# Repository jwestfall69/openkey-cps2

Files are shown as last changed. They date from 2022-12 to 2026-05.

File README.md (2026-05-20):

# openkey-cps2

* [Overview](#overview)
* [Project Status](#project-status)
* [Supported Games](#supported-games)
* [Hardware](#hardware)
   * [PCB Manufacturing](#pcb-manufacturing)
   * [BOM](#bom)
   * [Assembly](#assembly)
* [Programming](#programming)
  * [Hardware](#hardware-1)
  * [Software](#software)
  * [Testing](#testing)
* [Installation](#installation)
  * [93646B-3](#93646b-3)
  * [93646B-4](#93646b-4)
  * [93646B-5](#93646b-5)
  * [93646B-6](#93646b-6)
  * [93646B-7](#93646b-7)
  * [97691A-3 (all in one)](#97691a-3-all-in-one)
  * [97691A-4 (all in one)](#97691a-4-all-in-one)

## Overview
This is an opensource/hardware implementation of an on the fly CPS2 key programmer that consists of a board thats soldered onto the CPS2 B board or the CPS2 all-in-one boards.

**NOTE**: There is a typo on the silkscreen on hardware revision 2022-12-17.  The bypass cap is listed as being 100uf, when it should be 100nf.  This typo was fixed in hardware revision 2023-01-03, however the pictures below are all from the typo'd 2022-12-17 revision.

Individual boards:<br>
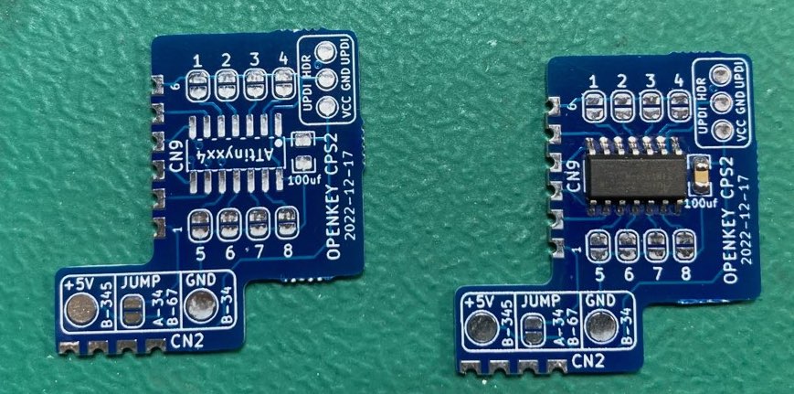
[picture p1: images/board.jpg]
board


Panel:<br>
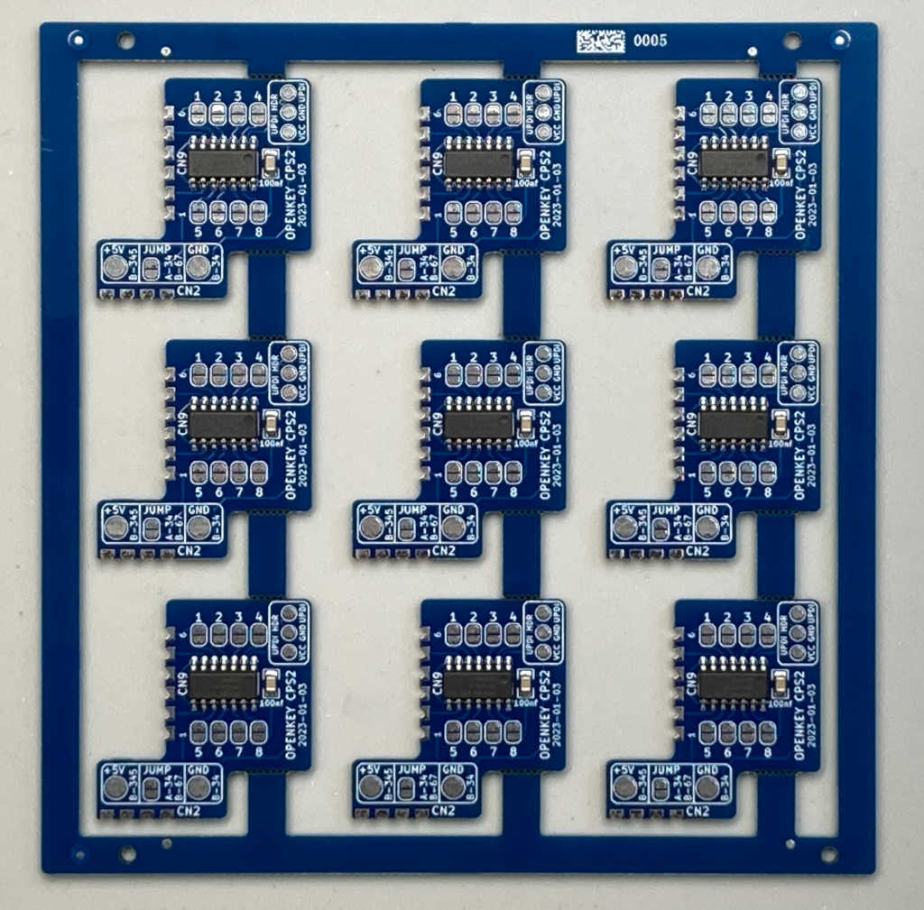
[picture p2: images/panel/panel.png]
pane


Details on *how* to program a CPS2 key data can be found in [Eduardo Cruz](http://arcadehacker.blogspot.com/)'s [write up](http://arcadehacker.blogspot.com/2016/09/capcom-cps2-security-programming-guide.html) and associated [firmware](https://github.com/ArcadeHacker/ArcadeHacker_CPS2).

Details on *what* to program can be found in MAME's [CPS2 driver](https://github.com/mamedev/mame/blob/master/src/mame/capcom/cps2.cpp) (the *.key files).

## Project Status
**PCB:** I would consider the design PCB done at this point.  I'm open to any input on changes/improvements as this is my first PCB design.

**Firmware:** Should be fulling working but more testing would be nice.  There are a lot of CPS2 games/keys.

**Documentation:** Work in progress

## Supported Games
**IMPORTANT**: You will want to program the ATtiny before soldering your game jumpers.  Specifically jumper #5 is also the programming pin on the ATtiny.  Jumping it will tie the pin to ground which will make programming impossible.

| Jumper<br>1234&nbsp;5678 | Program<br>ROM Labels | Mame<br>Rom Set | Game Names |
|:---:|:---|:---|:---|
| 0000&nbsp;0000 | nffe | 1944 | 1944: The Loop Master (Euro 000620) |
| 0000 0001 | nffj | 1944j | 1944: The Loop Master (Japan 000620) |
| 0000 0010 | nffu | 1944u | 1944: The Loop Master (USA 000620) |
| 0000 0011 | 19xe | 19xx | 19XX: The War Against Destiny (Euro 960104) |
| 0000 0100 | 09xa<br>19xa | 19xxa<br>19xxar1 | 19XX: The War Against Destiny (Asia 960104)<br>19XX: The War Against Destiny (Asia 951207) |
| 0000 0101 | 19xb | 19xxb | 19XX: The War Against Destiny (Brazil 951218) |
| 0000 0110 | 19xh | 19xxh | 19XX: The War Against Destiny (Hispanic 951218) |
| 0000 0111 | 19xj-03b<br>19xj<br>19xj | 19xxj<br>19xxjr1<br>19xxjr2 | 19XX: The War Against Destiny (Japan 960104, yellow case)<br>19XX: The War Against Destiny (Japan 951225)<br>19XX: The War Against Destiny (Japan 951207) |
| 0000 1000 | 19xu | 19xxu | 19XX: The War Against Destiny (USA 951207) |
| 0000 1001 | pwge<br>pwge | armwar<br>armwarr1 | Armored Warriors (Euro 941024)<br>Armored Warriors (Euro 941011) |
| 0000 1010 | pwga<br>pwga | armwara<br>armwarar1 | Armored Warriors (Asia 941024)<br>Armored Warriors (Asia 940920) |
| 0000 1011 | pwgb | armwarb | Armored Warriors (Brazil 941024) |
| 0000 1100 | pwgu<br>pwgu | armwaru<br>armwaru1 | Armored Warriors (USA 941024)<br>Armored Warriors (USA 940920) |
| 0000 1101 | avpe | avsp | Alien vs. Predator (Euro 940520) |
| 0000 1110 | avpa | avspa | Alien vs. Predator (Asia 940520) |
| 0000 1111 | avph | avsph | Alien vs. Predator (Hispanic 940520) |
| 0001 0000 | avpj | avspj | Alien vs. Predator (Japan 940520) |
| 0001 0001 | avpu | avspu | Alien vs. Predator (USA 940520) |
| 0001 0010 | btce | batcir | Battle Circuit (Euro 970319) |
| 0001 0011 | btca | batcira | Battle Circuit (Asia 970319) |
| 0001 0100 | btcj | batcirj | Battle Circuit (Japan 970319) |
| 0001 0101 | tkoj | choko | Janpai Puzzle Choukou (Japan 010820) |
| 0001 0110 | csce<br>csce | csclub<br>csclub1 | Capcom Sports Club (Euro 971017)<br>Capcom Sports Club (Euro 970722) |
| 0001 0111 | csca | cscluba | Capcom Sports Club (Asia 970722) |
| 0001 1000 | csch | csclubh | Capcom Sports Club (Hispanic 970722) |
| 0001 1001 | cscj<br>cscj | csclubj<br>csclubjy | Capcom Sports Club (Japan 970722)<br>Capcom Sports Club (Japan 970722, yellow case) |
| 0001 1010 | cybe | cybots | Cyberbots: Fullmetal Madness (Euro 950424) |
| 0001 1011 | cybj | cybotsj | Cyberbots: Fullmetal Madness (Japan 950420) |
| 0001 1100 | cybu | cybotsu | Cyberbots: Fullmetal Madness (USA 950424) |
| 0001 1101 | dd2e<br>dd2e<br>dd2e<br>dd2e | ddsom<br>ddsomr1<br>ddsomr2<br>ddsomr3 | Dungeons & Dragons: Shadow over Mystara (Euro 960619)<br>Dungeons & Dragons: Shadow over Mystara (Euro 960223)<br>Dungeons & Dragons: Shadow over Mystara (Euro 960209)<br>Dungeons & Dragons: Shadow over Mystara (Euro 960208) |
| 0001 1110 | dd2a<br>dd2a | ddsoma<br>ddsomar1 | Dungeons & Dragons: Shadow over Mystara (Asia 960619)<br>Dungeons & Dragons: Shadow over Mystara (Asia 960208) |
| 0001 1111 | dd2b | ddsomb | Dungeons & Dragons: Shadow over Mystara (Brazil 960223) |
| 0010 0000 | dd2h | ddsomh | Dungeons & Dragons: Shadow over Mystara (Hispanic 960223) |
| 0010 0001 | dd2j<br>dd2j<br>dd2j | ddsomj<br>ddsomjr1<br>ddsomjr2 | Dungeons & Dragons: Shadow over Mystara (Japan 960619)<br>Dungeons & Dragons: Shadow over Mystara (Japan 960206)<br>Dungeons & Dragons: Shadow over Mystara (Japan 960223) |
| 0010 0010 | dd2u<br>dd2u | ddsomu<br>ddsomur1 | Dungeons & Dragons: Shadow over Mystara (USA 960619)<br>Dungeons & Dragons: Shadow over Mystara (USA 960209) |
| 0010 0011 | dade<br>dade | ddtod<br>ddtodr1 | Dungeons & Dragons: Tower of Doom (Euro 940412)<br>Dungeons & Dragons: Tower of Doom (Euro 940113) |
| 0010 0100 | dada<br>dada | ddtoda<br>ddtodar1 | Dungeons & Dragons: Tower of Doom (Asia 940412)<br>Dungeons & Dragons: Tower of Doom (Asia 940113) |
| 0010 0101 | dadh<br>dadh<br>dadh | ddtodh<br>ddtodhr1<br>ddtodhr2 | Dungeons & Dragons: Tower of Doom (Hispanic 940412)<br>Dungeons & Dragons: Tower of Doom (Hispanic 940125)<br>Dungeons & Dragons: Tower of Doom (Hispanic 940113) |
| 0010 0110 | dadj<br>dadj<br>dadj | ddtodj<br>ddtodjr1<br>ddtodjr2 | Dungeons & Dragons: Tower of Doom (Japan 940412)<br>Dungeons & Dragons: Tower of Doom (Japan 940125)<br>Dungeons & Dragons: Tower of Doom (Japan 940113) |
| 0010 0111 | dadu<br>dadu | ddtodu<br>ddtodur1 | Dungeons & Dragons: Tower of Doom (USA 940125)<br>Dungeons & Dragons: Tower of Doom (USA 940113) |
| 0010 1000 | gmde | dimahoo | Dimahoo (Euro 000121) |
| 0010 1001 | gmdu | dimahoou | Dimahoo (USA 000121) |
| 0010 1010 | vame | dstlk | Darkstalkers: The Night Warriors (Euro 940705) |
| 0010 1011 | vama | dstlka | Darkstalkers: The Night Warriors (Asia 940705) |
| 0010 1100 | vamh | dstlkh | Darkstalkers: The Night Warriors (Hispanic 940818) |
| 0010 1101 | vamu<br>vamu | dstlku<br>dstlkur1 | Darkstalkers: The Night Warriors (USA 940818)<br>Darkstalkers: The Night Warriors (USA 940705) |
| 0010 1110 | uece | ecofghtr | Eco Fighters (World 931203) |
| 0010 1111 | ueca | ecofghtra | Eco Fighters (Asia 931203) |
| 0011 0000 | uech | ecofghtrh | Eco Fighters (Hispanic 931203) |
| 0011 0001 | uecu<br>uecu | ecofghtru<br>ecofghtru1 | Eco Fighters (USA 940215)<br>Eco Fighters (USA 931203) |
| 0011 0010 | ggwu | gigawing | Giga Wing (USA 990222) |
| 0011 0011 | ggwa | gigawinga | Giga Wing (Asia 990222) |
| 0011 0100 | ggwb | gigawingb | Giga Wing (Brazil 990222) |
| 0011 0101 | ggwh | gigawingh | Giga Wing (Hispanic 990222) |
| 0011 0110 | ggwj | gigawingj | Giga Wing (Japan 990223) |
| 0011 0111 | gmdj | gmahou | Great Mahou Daisakusen (Japan 000121) |
| 0011 1000 | hs2u | hsf2 | Hyper Street Fighter II: The Anniversary Edition (USA 040202) |
| 0011 1001 | hs2a | hsf2a | Hyper Street Fighter II: The Anniversary Edition (Asia 040202) |
| 0011 1010 | hs2j<br>hs2j | hsf2j<br>hsf2j1<br>hsf2j2 | Hyper Street Fighter II: The Anniversary Edition (Japan 040202)<br>Street Fighter II: The Anniversary Edition (Japan 040123)<br>Hyper Street Fighter II: The Anniversary Edition (Japan 031222) |
| 0011 1011 | majj | jyangoku | Jyangokushi: Haoh no Saihai (Japan 990527) |
| 0011 1100 | rm2u | megaman2 | Mega Man 2: The Power Fighters (USA 960708) |
| 0011 1101 | rm2a | megaman2a | Mega Man 2: The Power Fighters (Asia 960708) |
| 0011 1110 | rm2h | megaman2h | Mega Man 2: The Power Fighters (Hispanic 960712) |
| 0011 1111 | rcmu<br>rcmu<br>rcmu | mmancp2u<br>mmancp2ur1<br>mmancp2ur2 | Mega Man: The Power Battle (CPS2, USA 951006, SAMPLE Version)<br>Mega Man: The Power Battle (CPS2, USA 950926, SAMPLE Version)<br>Mega Man: The Power Battle (CPS2, USA 950925, SAMPLE Version) |
| 0100 0000 | sys_rom1 | mmatrix | Mars Matrix: Hyper Solid Shooting (USA 000412) |
| 0100 0001 | mmxa | mmatrixa | Mars Matrix: Hyper Solid Shooting (Asia 000412) |
| 0100 0010 | mmxj | mmatrixj | Mars Matrix: Hyper Solid Shooting (Japan 000412) |
| 0100 0011 | mpne<br>mpn_03a<br>mpnj<br>mpne<br>mpnu | mpang<br>mpanga<br>mpangj<br>mpangr1<br>mpangu | Mighty! Pang (Euro 001010)<br>Mighty! Pang (Asia 001010)<br>Mighty! Pang (Japan 001011)<br>Mighty! Pang (Euro 000925)<br>Mighty! Pang (USA 001010) |
| 0100 0100 | mshe | msh | Marvel Super Heroes (Euro 951024) |
| 0100 0101 | msha | msha | Marvel Super Heroes (Asia 951024) |
| 0100 0110 | mshb<br>mshb | mshb<br>mshbr1 | Marvel Super Heroes (Brazil 951117)<br>Marvel Super Heroes (Brazil 951024) |
| 0100 0111 | mshh | mshh | Marvel Super Heroes (Hispanic 951117) |
| 0100 1000 | mshj<br>mshj | mshj<br>mshjr1 | Marvel Super Heroes (Japan 951117)<br>Marvel Super Heroes (Japan 951024) |
| 0100 1001 | mshu | mshu | Marvel Super Heroes (USA 951024) |
| 0100 1010 | mvse | mshvsf | Marvel Super Heroes Vs. Street Fighter (Euro 970625) |
| 0100 1011 | mvsa<br>mvsa | mshvsfa<br>mshvsfa1 | Marvel Super Heroes Vs. Street Fighter (Asia 970625)<br>Marvel Super Heroes Vs. Street Fighter (Asia 970620) |
| 0100 1100 | mvsb<br>mvsb | mshvsfb<br>mshvsfb1 | Marvel Super Heroes Vs. Street Fighter (Brazil 970827)<br>Marvel Super Heroes Vs. Street Fighter (Brazil 970625) |
| 0100 1101 | mvsh | mshvsfh | Marvel Super Heroes Vs. Street Fighter (Hispanic 970625) |
| 0100 1110 | mvsj<br>mvsj<br>mvsj | mshvsfj<br>mshvsfj1<br>mshvsfj2 | Marvel Super Heroes Vs. Street Fighter (Japan 970707)<br>Marvel Super Heroes Vs. Street Fighter (Japan 970702)<br>Marvel Super Heroes Vs. Street Fighter (Japan 970625) |
| 0100 1111 | mvsu<br>mvsu | mshvsfu<br>mshvsfu1 | Marvel Super Heroes Vs. Street Fighter (USA 970827)<br>Marvel Super Heroes Vs. Street Fighter (USA 970625) |
| 0101 0000 | mvce<br>mvce | mvsc<br>mvscr1 | Marvel Vs. Capcom: Clash of Super Heroes (Euro 980123)<br>Marvel Vs. Capcom: Clash of Super Heroes (Euro 980112) |
| 0101 0001 | mvca<br>mvca | mvsca<br>mvscar1 | Marvel Vs. Capcom: Clash of Super Heroes (Asia 980123)<br>Marvel Vs. Capcom: Clash of Super Heroes (Asia 980112) |
| 0101 0010 | mvcb | mvscb | Marvel Vs. Capcom: Clash of Super Heroes (Brazil 980123) |
| 0101 0011 | mvch | mvsch | Marvel Vs. Capcom: Clash of Super Heroes (Hispanic 980123) |
| 0101 0100 | mvcj<br>mvcj<br>mvc_ja | mvscj<br>mvscjr1<br>mvscjsing | Marvel Vs. Capcom: Clash of Super Heroes (Japan 980123)<br>Marvel Vs. Capcom: Clash of Super Heroes (Japan 980112)<br>Marvel Vs. Capcom: Clash of Super Heroes (Japan 980123) (Single PCB) |
| 0101 0101 | mvcu<br>mvcu | mvscu<br>mvscur1 | Marvel Vs. Capcom: Clash of Super Heroes (USA 980123)<br>Marvel Vs. Capcom: Clash of Super Heroes (USA 971222) |
| 0101 0110 | vphe | nwarr | Night Warriors: Darkstalkers' Revenge (Euro 950316) |
| 0101 0111 | vpha | nwarra | Night Warriors: Darkstalkers' Revenge (Asia 950302) |
| 0101 1000 | vphb | nwarrb | Night Warriors: Darkstalkers' Revenge (Brazil 950403) |
| 0101 1001 | vphh | nwarrh | Night Warriors: Darkstalkers' Revenge (Hispanic 950403) |
| 0101 1010 | vphu | nwarru | Night Warriors: Darkstalkers' Revenge (USA 950406) |
| 0101 1011 | pcfj | pfghtj | Pocket Fighter (Japan 970904) |
| 0101 1100 | pwgj<br>pwgj | pgear<br>pgearr1 | Powered Gear: Strategic Variant Armor Equipment (Japan 941024)<br>Powered Gear: Strategic Variant Armor Equipment (Japan 940916) |
| 0101 1101 | pgau | progear | Progear (USA 010117) |
| 0101 1110 | pgaa | progeara | Progear (Asia 010117) |
| 0101 1111 | pgaj | progearj | Progear no Arashi (Japan 010117) |
| 0110 0000 | pl2e<br>pl2j<br>pl2j | pzloop2<br>pzloop2j<br>pzloop2jr1 | Puzz Loop 2 (Euro 010302)<br>Puzz Loop 2 (Japan 010226)<br>Puzz Loop 2 (Japan 010205) |
| 0110 0001 | tqzj | qndream | Quiz Nanairo Dreams: Nijiirochou no Kiseki (Japan 96086) |
| 0110 0010 | smbe | ringdest | Ring of Destruction: Slammasters II (Euro 940902) |
| 0110 0011 | smba | ringdesta | Ring of Destruction: Slammasters II (Asia 940831) |
| 0110 0100 | smbb<br>smbh | ringdestb<br>ringdesth | Ring of Destruction: Slammasters II (Brazil 940902)<br>Ring of Destruction: Slammasters II (Hispanic 940902) |
| 0110 0101 | rcmj | rmancp2j | Rockman: The Power Battle (CPS2, Japan 950922) |
| 0110 0110 | rm2j | rockman2j | Rockman 2: The Power Fighters (Japan 960708) |
| 0110 0111 | sfze<br>sfze<br>sfze<br>sfze | sfa<br>sfar1<br>sfar2<br>sfar3 | Street Fighter Alpha: Warriors' Dreams (Euro 950727)<br>Street Fighter Alpha: Warriors' Dreams (Euro 950718)<br>Street Fighter Alpha: Warriors' Dreams (Euro 950627)<br>Street Fighter Alpha: Warriors' Dreams (Euro 950605) |
| 0110 1000 | sz2e | sfa2 | Street Fighter Alpha 2 (Euro 960229) |
| 0110 1001 | sz2u<br>sz2u | sfa2u<br>sfa2ur1 | Street Fighter Alpha 2 (USA 960430)<br>Street Fighter Alpha 2 (USA 960306) |
| 0110 1010 | sz3e | sfa3 | Street Fighter Alpha 3 (Euro 980904) |
| 0110 1011 | sz3b | sfa3b | Street Fighter Alpha 3 (Brazil 980629) |
| 0110 1100 | sz3h<br>sz3h | sfa3h<br>sfa3hr1 | Street Fighter Alpha 3 (Hispanic 980904)<br>Street Fighter Alpha 3 (Hispanic 980629) |
| 0110 1101 | sz3u<br>sz3u<br>sz3-usam_03 | sfa3u<br>sfa3ur1<br>sfa3us | Street Fighter Alpha 3 (USA 980904)<br>Street Fighter Alpha 3 (USA 980629)<br>Street Fighter Alpha 3 (USA 980616, SAMPLE Version) |
| 0110 1110 | sfzu | sfau | Street Fighter Alpha: Warriors' Dreams (USA 950627) |
| 0110 1111 | sz2a | sfz2a | Street Fighter Zero 2 (Asia 960227) |
| 0111 0000 | szaa<br>szaa | sfz2al<br>sfz2alr1 | Street Fighter Zero 2 Alpha (Asia 960826)<br>Street Fighter Zero 2 Alpha (Asia 960805) |
| 0111 0001 | szab | sfz2alb | Street Fighter Zero 2 Alpha (Brazil 960813) |
| 0111 0010 | szah | sfz2alh | Street Fighter Zero 2 Alpha (Hispanic 960813) |
| 0111 0011 | szaj | sfz2alj | Street Fighter Zero 2 Alpha (Japan 960805) |
| 0111 0100 | sz2b<br>sz2b | sfz2b<br>sfz2br1 | Street Fighter Zero 2 (Brazil 960531)<br>Street Fighter Zero 2 (Brazil 960304) |
| 0111 0101 | sz2h | sfz2h | Street Fighter Zero 2 (Hispanic 960304) |
| 0111 0110 | sz2j<br>sz2j | sfz2j<br>sfz2jr1 | Street Fighter Zero 2 (Japan 960430)<br>Street Fighter Zero 2 (Japan 960227) |
| 0111 0111 | sz2n | sfz2n | Street Fighter Zero 2 (Oceania 960229) |
| 0111 1000 | sz3a<br>sz3a | sfz3a<br>sfz3ar1 | Street Fighter Zero 3 (Asia 980904)<br>Street Fighter Zero 3 (Asia 980701) |
| 0111 1001 | sz3j<br>sz3j<br>sz3j | sfz3j<br>sfz3jr1<br>sfz3jr2 | Street Fighter Zero 3 (Japan 980904)<br>Street Fighter Zero 3 (Japan 980727)<br>Street Fighter Zero 3 (Japan 980629) |
| 0111 1010 | sfza<br>sfza | sfza<br>sfzar1 | Street Fighter Zero (Asia 950627)<br>Street Fighter Zero (Asia 950605) |
| 0111 1011 | sfzb<br>sfzb | sfzb<br>sfzbr1 | Street Fighter Zero (Brazil 951109)<br>Street Fighter Zero (Brazil 950727) |
| 0111 1100 | sfzh<br>sfzh | sfzh<br>sfzhr1 | Street Fighter Zero (Hispanic 950718)<br>Street Fighter Zero (Hispanic 950627) |
| 0111 1101 | sfzj<br>sfzj<br>sfzj | sfzj<br>sfzjr1<br>sfzjr2 | Street Fighter Zero (Japan 950727)<br>Street Fighter Zero (Japan 950627)<br>Street Fighter Zero (Japan 950605) |
| 0111 1110 | pcfu | sgemf | Super Gem Fighter Mini Mix (USA 970904) |
| 0111 1111 | pcfa | sgemfa | Super Gem Fighter: Mini Mix (Asia 970904) |
| 1000 0000 | pcfh | sgemfh | Super Gem Fighter: Mini Mix (Hispanic 970904) |
| 1000 0001 | smbj<br>smbj | smbomb<br>smbombr1 | Super Muscle Bomber: The International Blowout (Japan 940831)<br>Super Muscle Bomber: The International Blowout (Japan 940808) |
| 1000 0010 | pzfe | spf2t | Super Puzzle Fighter II Turbo (Euro 960529) |
| 1000 0011 | pzfa | spf2ta | Super Puzzle Fighter II Turbo (Asia 960529) |
| 1000 0100 | pzfh | spf2th | Super Puzzle Fighter II Turbo (Hispanic 960531) |
| 1000 0101 | pzfu | spf2tu | Super Puzzle Fighter II Turbo (USA 960620) |
| 1000 0110 | pzfj | spf2xj | Super Puzzle Fighter II X (Japan 960531) |
| 1000 0111 | ssfe<br>ssfe | ssf2<br>ssf2r1 | Super Street Fighter II: The New Challengers (World 931005)<br>Super Street Fighter II: The New Challengers (World 930911) |
| 1000 1000 | ssfa<br>ssfa | ssf2a<br>ssf2ar1 | Super Street Fighter II: The New Challengers (Asia 931005)<br>Super Street Fighter II: The New Challengers (Asia 930914) |
| 1000 1001 | ssfh | ssf2h | Super Street Fighter II: The New Challengers (Hispanic 930911) |
| 1000 1010 | ssfj<br>ssfj<br>ssfj | ssf2j<br>ssf2jr1<br>ssf2jr2 | Super Street Fighter II: The New Challengers (Japan 931005)<br>Super Street Fighter II: The New Challengers (Japan 930911)<br>Super Street Fighter II: The New Challengers (Japan 930910) |
| 1000 1011 | ssfh | ssf2t | Super Street Fighter II Turbo (World 940223) |
| 1000 1100 | sfxa | ssf2ta | Super Street Fighter II Turbo (Asia 940223) |
| 1000 1101 | ssfe<br>ssfe | ssf2tb<br>ssf2tbr1 | Super Street Fighter II: The Tournament Battle (World 931119)<br>Super Street Fighter II: The Tournament Battle (World 930911) |
| 1000 1110 | ssfa | ssf2tba | Super Street Fighter II: The Tournament Battle (Asia 931005) |
| 1001 0000 | ssftj<br>ssfj | ssf2tbj<br>ssf2tbj1 | Super Street Fighter II: The Tournament Battle (Japan 931005)<br>Super Street Fighter II: The Tournament Battle (Japan 930911) |
| 1001 0001 | ssfu | ssf2tbu | Super Street Fighter II: The Tournament Battle (USA 930911) |
| 1001 0010 | sfxh | ssf2th | Super Street Fighter II Turbo (Hispanic 940223) |
| 1001 0011 | sfxu<br>sfxu | ssf2tu<br>ssf2tur1 | Super Street Fighter II Turbo (USA 940323)<br>Super Street Fighter II Turbo (USA 940223) |
| 1001 0100 | ssfu<br>ssfu | ssf2u<br>ssf2us2 | Super Street Fighter II: The New Challengers (USA 930911)<br> |
| 1001 0101 | sfxj<br>sfxj | ssf2xj<br>ssf2xjr1 | Super Street Fighter II X: Grand Master Challenge (Japan 940311)<br>Super Street Fighter II X: Grand Master Challenge (Japan 940223) |
| 1001 0110 | sfxo | ssf2xjr1r | Super Street Fighter II X: Grand Master Challenge (Japan 940223 rent version) |
| 1001 0111 | uecj | uecology | Ultimate Ecology (Japan 931203) |
| 1001 1000 | vamj<br>vamj<br>vamj | vampj<br>vampja<br>vampjr1 | Vampire: The Night Warriors (Japan 940705)<br>Vampire: The Night Warriors (Japan 940705 alt)<br>Vampire: The Night Warriors (Japan 940630) |
| 1001 1001 | vh2j<br>vh2j | vhunt2<br>vhunt2r1 | Vampire Hunter 2: Darkstalkers Revenge (Japan 970929)<br>Vampire Hunter 2: Darkstalkers Revenge (Japan 970913) |
| 1001 1010 | vphj<br>vphj<br>vphjstop<br>vphj | vhuntj<br>vhuntjr1<br>vhuntjr1s<br>vhuntjr2 | Vampire Hunter: Darkstalkers' Revenge (Japan 950316)<br>Vampire Hunter: Darkstalkers' Revenge (Japan 950307)<br>Vampire Hunter: Darkstalkers' Revenge (Japan 950307 stop version)<br>Vampire Hunter: Darkstalkers' Revenge (Japan 950302) |
| 1001 1011 | vm3e | vsav | Vampire Savior: The Lord of Vampire (Euro 970519) |
| 1001 1100 | vs2j | vsav2 | Vampire Savior 2: The Lord of Vampire (Japan 970913) |
| 1001 1101 | vm3a | vsava | Vampire Savior: The Lord of Vampire (Asia 970519) |
| 1001 1110 | vm3b | vsavb | Vampire Savior: The Lord of Vampire (Brazil 970519) |
| 1001 1111 | vm3h | vsavh | Vampire Savior: The Lord of Vampire (Hispanic 970519) |
| 1010 0000 | vm3j | vsavj | Vampire Savior: The Lord of Vampire (Japan 970519) |
| 1010 0001 | vm3u | vsavu | Vampire Savior: The Lord of Vampire (USA 970519) |
| 1010 0010 | xmne<br>xmne | xmcota<br>xmcotar1 | X-Men: Children of the Atom (Euro 950331)<br>X-Men: Children of the Atom (Euro 950105) |
| 1010 0011 | xmna<br>xmna<br>xmna | xmcotaa<br>xmcotaar1<br>xmcotaar2 | X-Men: Children of the Atom (Asia 950105)<br>X-Men: Children of the Atom (Asia 941219)<br>X-Men: Children of the Atom (Asia 941217) |
| 1010 0100 | xmnb | xmcotab | X-Men: Children of the Atom (Brazil 950331) |
| 1010 0101 | xmnh<br>xmnh | xmcotah<br>xmcotahr1 | X-Men: Children of the Atom (Hispanic 950331)<br>X-Men: Children of the Atom (Hispanic 950105) |
| 1010 0110 | xmnj<br>xmnj<br>xmnj<br>xmnj<br>xmno | xmcotaj<br>xmcotaj1<br>xmcotaj2<br>xmcotaj3<br>xmcotajr | X-Men: Children of the Atom (Japan 950105)<br>X-Men: Children of the Atom (Japan 941222)<br>X-Men: Children of the Atom (Japan 941219)<br>X-Men: Children of the Atom (Japan 941217)<br>X-Men: Children of the Atom (Japan 941208 rent version) |
| 1010 0111 | xmnu | xmcotau | X-Men: Children of the Atom (USA 950105) |
| 1010 1000 | xvse<br>xvse | xmvsf<br>xmvsfr1 | X-Men Vs. Street Fighter (Euro 961004)<br>X-Men Vs. Street Fighter (Euro 960910) |
| 1010 1001 | xvsa<br>xvsa<br>xvsa<br>xvsa | xmvsfa<br>xmvsfar1<br>xmvsfar2<br>xmvsfar3 | X-Men Vs. Street Fighter (Asia 961023)<br>X-Men Vs. Street Fighter (Asia 961004)<br>X-Men Vs. Street Fighter (Asia 960919)<br>X-Men Vs. Street Fighter (Asia 960910) |
| 1010 1010 | xvsb | xmvsfb | X-Men Vs. Street Fighter (Brazil 961023) |
| 1010 1011 | xvsh | xmvsfh | X-Men Vs. Street Fighter (Hispanic 961004) |
| 1010 1100 | xvsj<br>xvsj<br>xvsj<br>xvsj | xmvsfj<br>xmvsfjr1<br>xmvsfjr2<br>xmvsfjr3<br>xmvsfjr4 | X-Men Vs. Street Fighter (Japan 970113)<br>X-Men Vs. Street Fighter (Japan 961023)<br>X-Men Vs. Street Fighter (Japan 961004)<br>X-Men Vs. Street Fighter (Japan 960910)<br>X-Men Vs. Street Fighter (Japan 960909) |
| 1010 1101 | xvsu<br>xvsu<br>xvsu | xmvsfu<br>xmvsfur1<br>xmvsfur2 | X-Men Vs. Street Fighter (USA 961023)<br>X-Men Vs. Street Fighter (USA 961004)<br>X-Men Vs. Street Fighter (USA 960910) |
| 1010 1110 | | | Phoenix Key (0xff filled) |

## Hardware
### PCB Manufacturing
For thickness I've been using 1mm, but standard 1.6mm will work fine too.

The board has 2 sets of castellated holes (through holes cut in half on the edge of the board).  When ordering make sure you pick the option for castellated holes as they require special processing.  If you don't pick the option, your castellated holes will likely be mangled and look like this

**Mangled Castellated Holes**<br>
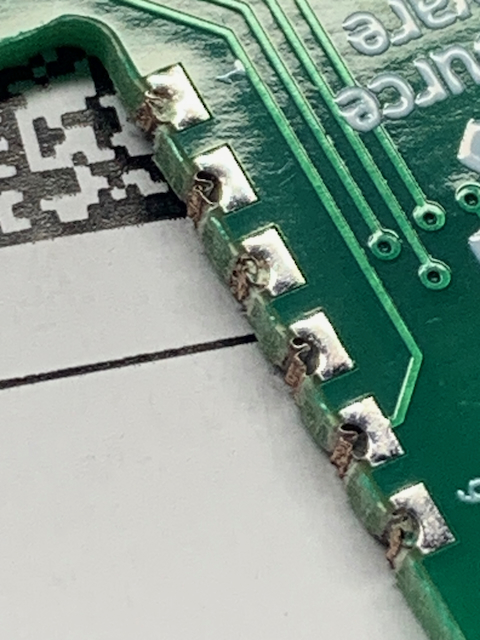
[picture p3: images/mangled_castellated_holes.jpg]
mangled castellated holes


I've been using [jlcpcb](https://jlcpcb.com/) for PCB manufacturing.  For them, picking castellated holes adds around a $40 fee to the order.  They also seem to have an unwritten limit of 30 PCBs per order that have castellated holes.  If you go above this they may reject your order or ask you if its ok to remove the castellated holes option (don't do it!).

If you want more then 30 PCBs or want them assembled you will want to use the
panel version of openkey-cps2.  More detail regarding this can be found in [PANEL.md](PANEL.md).

### BOM
| Description | Part Number | DigiKey | Mouser | Notes |
|---|---|---|---|---|
| ATtiny404 20Mhz | ATTINY404-SSN | [ATTINY404-SSN-ND](https://www.digikey.com/en/products/detail/microchip-technology/ATTINY404-SSN/9947546) | [556-ATTINY404-SSNR](https://www.mouser.com/ProductDetail/Microchip-Technology-Atmel/ATTINY404-SSNR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) | Other ATtiny tinyAVR 0/1/2-series models should be viable as well.  The code compiles to a little over 3K in size, so any that have 4K or more of flash should work.  Just note I have only tested with 404s |
| 100nf / 0.1uf SMD Ceramic Capacitor 0805 Size | | | | |

### Assembly
Nothing special here just install the ATtiny and the bypass cap.

**IMPORTANT**: You will want to program the ATtiny before soldering your game jumpers.  Specifically jumper #5 is also the programming pin on the ATtiny.  Jumping it will tie the pin to ground which will make programming impossible.

## Programming
### Hardware
Programming is done with a UPDI programmer.  I've been using this one:

[Serial UPDI Programmer for ATmega 0-Series, or ATtiny 0-Series or 1-Series, or AVR DA or AVR DB](https://www.amazon.com/dp/B09X64YRLD?psc=1&ref=ppx_yo2ov_dt_b_product_details)

Note: This programmer (and likely others) has a switch for 3.3V and 5V.  Set it to 5V.

The openkey-cps2 programming port consists of 3x pads (VCC, GND, UPDI) that will need to be connected to the programmer.  I've been using a short 3 pin female to female IDC cable with [pogo pins](https://www.amazon.com/dp/B00X7C8PGE?psc=1&ref=ppx_yo2ov_dt_b_product_details) on one end to do this.  Additionally you could probably use something like [this](https://www.amazon.com/dp/B09MGG4C6X?ref=ppx_yo2ov_dt_b_product_details&th=1) if you are going to be programming a bunch.

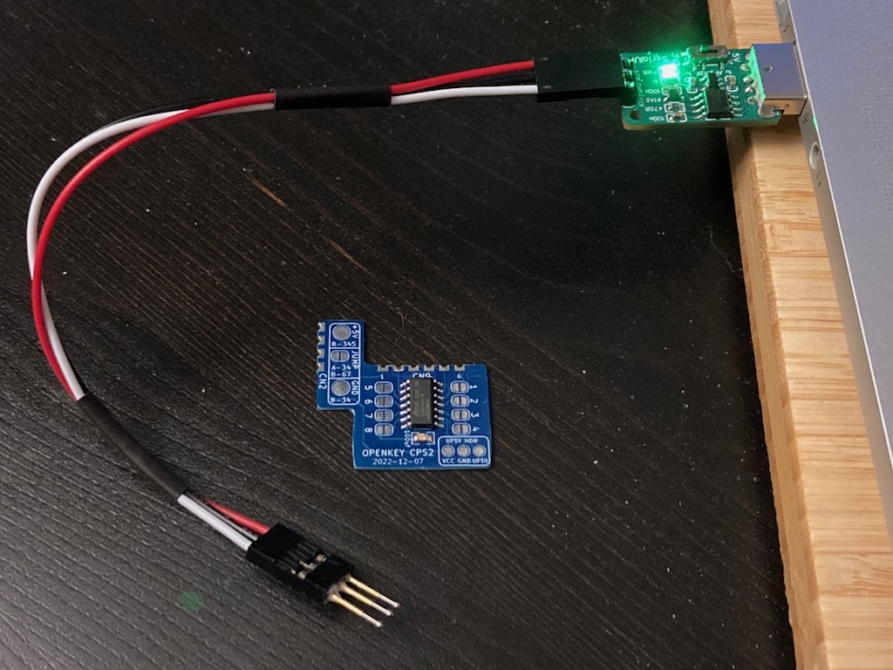
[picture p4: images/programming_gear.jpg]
programming gear


Of course be sure you properly orient the board so the labeled pads match up.  vcc to vcc, gnd to gnd, and updi to updi.

### Software
For software I've been using the [Arduino IDE](https://www.arduino.cc/en/software/OldSoftwareReleases) with [megaTinyCore](https://github.com/SpenceKonde/megaTinyCore), which adds support for tinyAVR 0/1/2-Series MCUs.

**NOTE**: The makers of megaTinyCore currently recommend using Arduino IDE version 1.8.13 for best compatibility.
 2.0 definitely does not work!

To install the megaTinyCore you, should just need to add http://drazzy.com/package_drazzy.com_index.json to "Addit
ional Boards Manager URLs" in the settings for the Arduino IDE.

From there you need to configure the board/programming settings.  I've been using these:

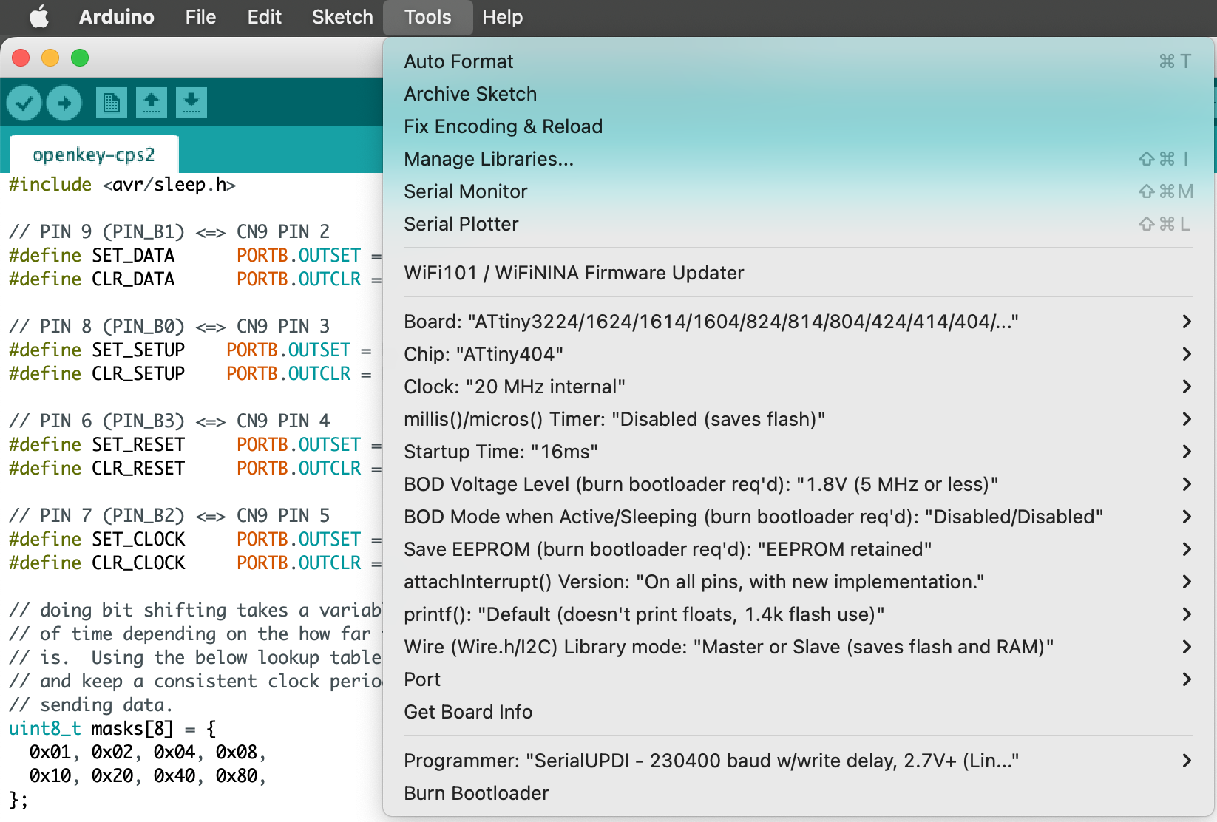
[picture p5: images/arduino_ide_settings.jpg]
arduino ide settings


### Testing
If you are selling or giving away the openkey-cps2's that you have assembled/programmed its nice to be able to test them first.  This section explains how you can test the board without having to install it.

You will need to get your hands on a "1944: The Loop Master (Euro 000620)" in a 93646B-6 or 93646B-7 B board.  For mine I just made a conversion using the 1944 mame romset.  This specific game is needed because its game jumper 0000 0000.

Additionally you will need to create the following cable

Side A:<br>
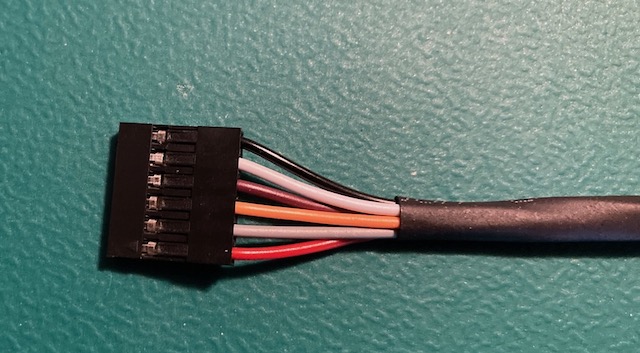
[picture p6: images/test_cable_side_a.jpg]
test cable side a


Side B:<br>
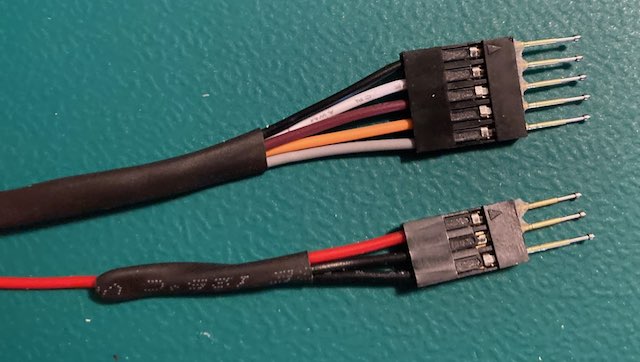
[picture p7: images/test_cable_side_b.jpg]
test cable side b


I would advise making this cable about 24 inches long.

You will note that side "A" is 6 pin female connectors, which break out into a 5 pin female connector and 3 pin female connector "B" side.  The "B" side then has pogo pins installed with super glue to keep them steady.  Additionally on the 3 pin female connector "B" side, pins 2 and 3 are just connected to each other.

The red wire is +5V, black wire is GND, remaining are data lines.

The "A" side 6 pin connector should be plugged into CN9 on the B board, with +5V on pin 1, and GND on pin 6 as shown.

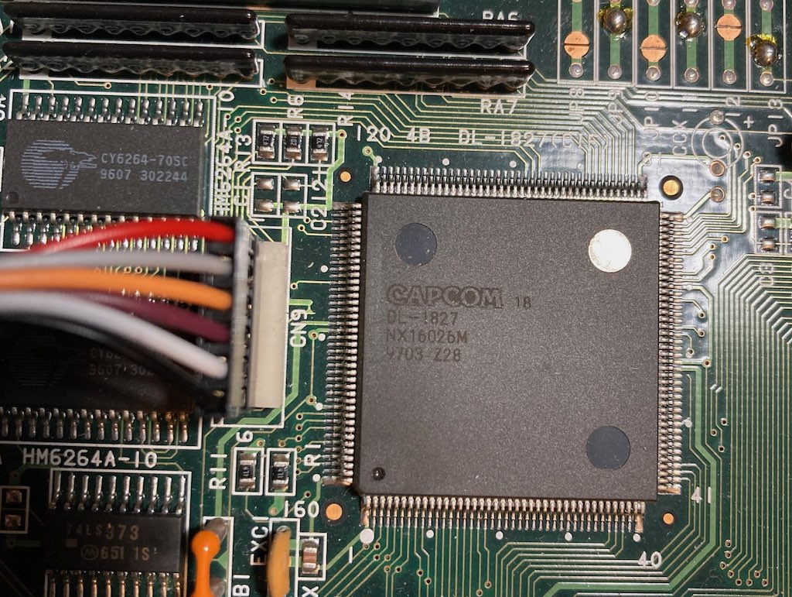
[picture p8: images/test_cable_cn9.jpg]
test cable cn9


**IMPORTANT**: The +5V on the 3 pin female/pogo pin connector will be live when you power on the board, so be extra careful you don't touch anything with it or it could cause a short/damage.

CPS2 boards will hold onto the programmed key data for a while after they have been powered off.  So to properly test the openkey-cps2 its best to program the wrong key, verify it breaks the game, then program the correct key to verify it works.

**Programming the WRONG key**
1. Power on the CPS2 board
2. Connect the 5 pogo pin connector to pins 2-6 of CN9 on the openkey-cps2
3. Connect the 3 pogo pin connector to the UPDI header on openkey-cps2, with the red wire connected to VCC pad, and the pins 2-3 connected to GND and UPDI pads

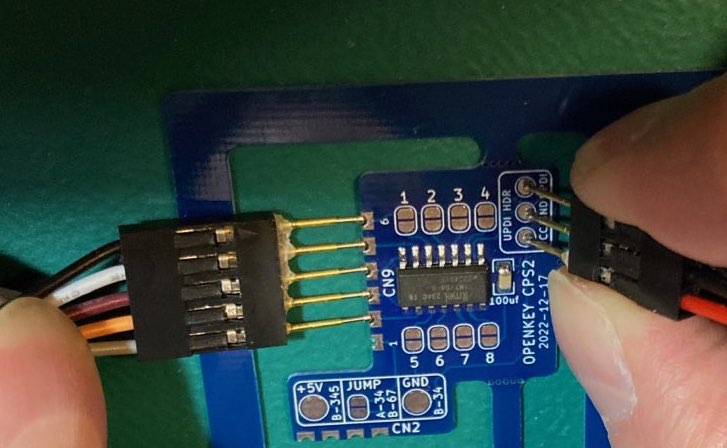
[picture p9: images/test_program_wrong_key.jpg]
test program wrong key


This should result is a solid color screen, mine is normally purple.

The UPDI pad on the UPDI header is shared with jumper #5 of the game select.  By jumping the GND and UPDI pads together its cause the MCU to program game 0000 1000 or 19XX: The War Against Destiny (USA 951207), which is the wrong key for 1944: The Loop Master (Euro 000620)

**Programming the CORRECT key**
1. Remove both the 5 pogo pin and 3 pogo pin connectors from the openkey-cps2 board
2. Connect the 5 pogo pin connector to pins 2-6 of CN9 on the openkey-cps2
3. Using the 3 pogo pin connector, only connect the red wire pogo pin to the VCC pad on the UPDI header.  Do not connect anything to the GND and UPDI pads

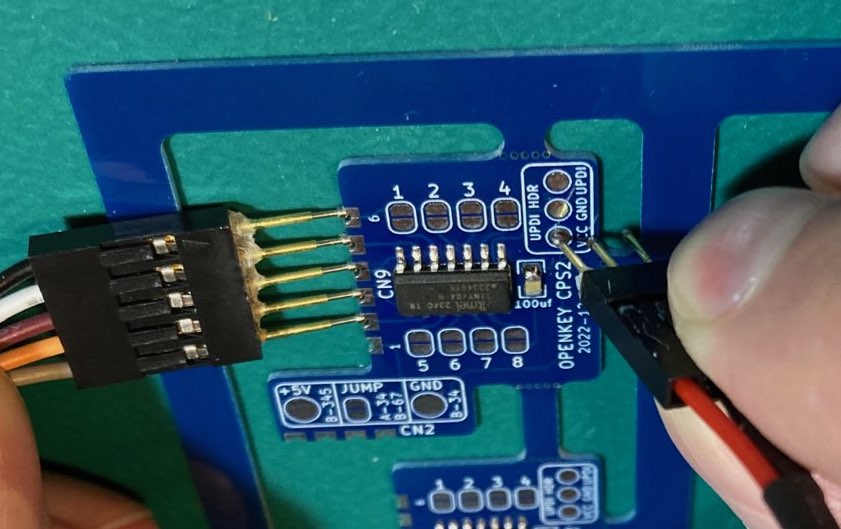
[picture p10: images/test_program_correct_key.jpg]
test program correct key


By only applying +5V on the VCC pad on UPDI header and NOT jumping the GND/UPDI pads it will cause the MCU to program game 0000 0000.

The game should boot a few seconds later

You do not need to power off the CPS2 board in between programming the wrong/correct key or even between testing multiple openkey-cps2 board.  Part of the programming process will reset the game.

## Installation
Below are pictures for installing openkey-cps2 on the different cps2 board revisions.  

You will notice there are 3 boxes on the board, 2 with solder pads (+5V and GND), and 1 jumper.  Within the box is a short hand version of which board revisions need which of them.

  * +5V has **B-345** which means its needed for revisions 93646**B-3**, 93646**B-4**, and 93646**B-5**
  * JUMP has **B-67** and **A-34** which means it needs to be jumped for revisions 93646**B-6**, 93646**B-7**, 97691**A-3** and 97691**A-4**
  * GND has **B-34** which means its needed for revisions 93646**B-3** and 93646**B-4**

### **93646B-3**
### **93646B-4**
---
93646B-3 and 93646B-4 have the same install process.

Identify CN2 on the top side of the CPS2 B Board PCB.  This is where openkey-cps2 will be installed.

Your board will likely have the resistor shown in the below picture.
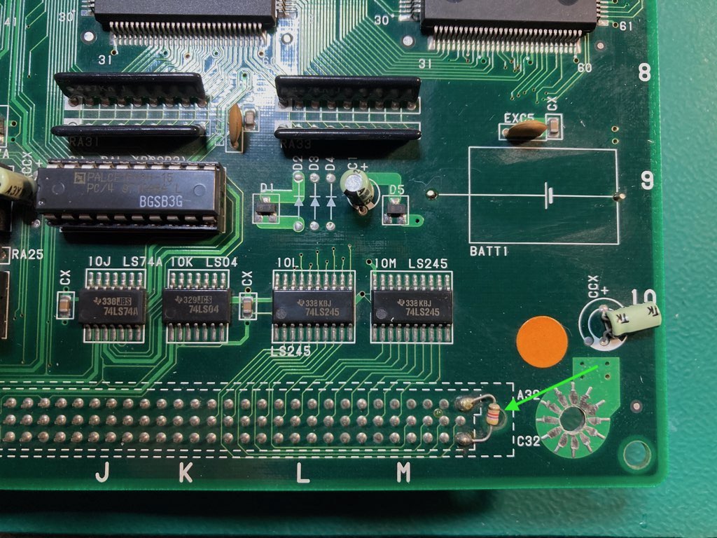
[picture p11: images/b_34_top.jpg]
b-34-top


Temporarily desolder the top connection of the resistor, move it out of the way and install openkey-cps2 as shown below.  Additionally make note of the red and green arrows/lines as these will be the locations we wire up for +5V and GND.

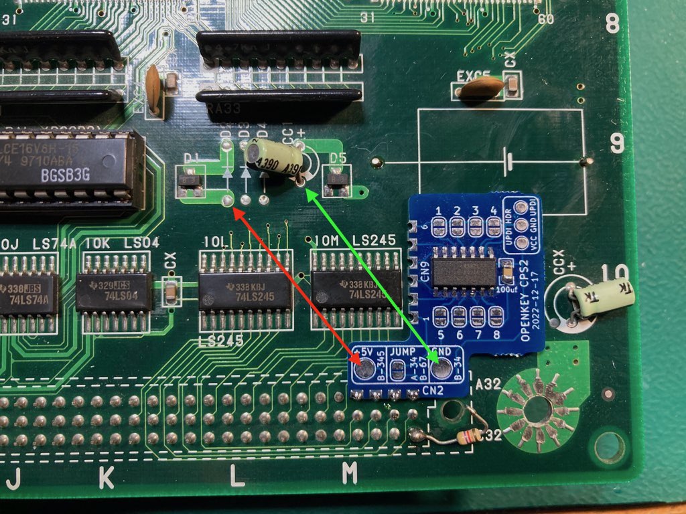
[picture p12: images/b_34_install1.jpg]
b-34-install1


Re-solder the resistor and wire up the +5V and GND wires as shown below.  Then jumper 1 to 8 based on which game you need. 

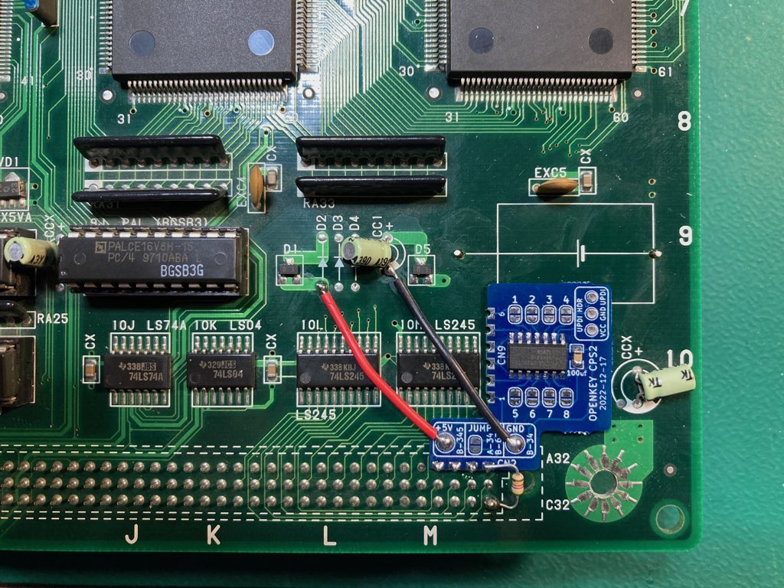
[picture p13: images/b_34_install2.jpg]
b-34-install2


### **93646B-5**
---
NOTE: I don't have a 93646B-5, but this is what should be required for the installation.

Identify CN9 on the top side of the CPS2 B Board PCB.  The underside of CN9 is what we will be installing openkey-cps2 to.

Top:
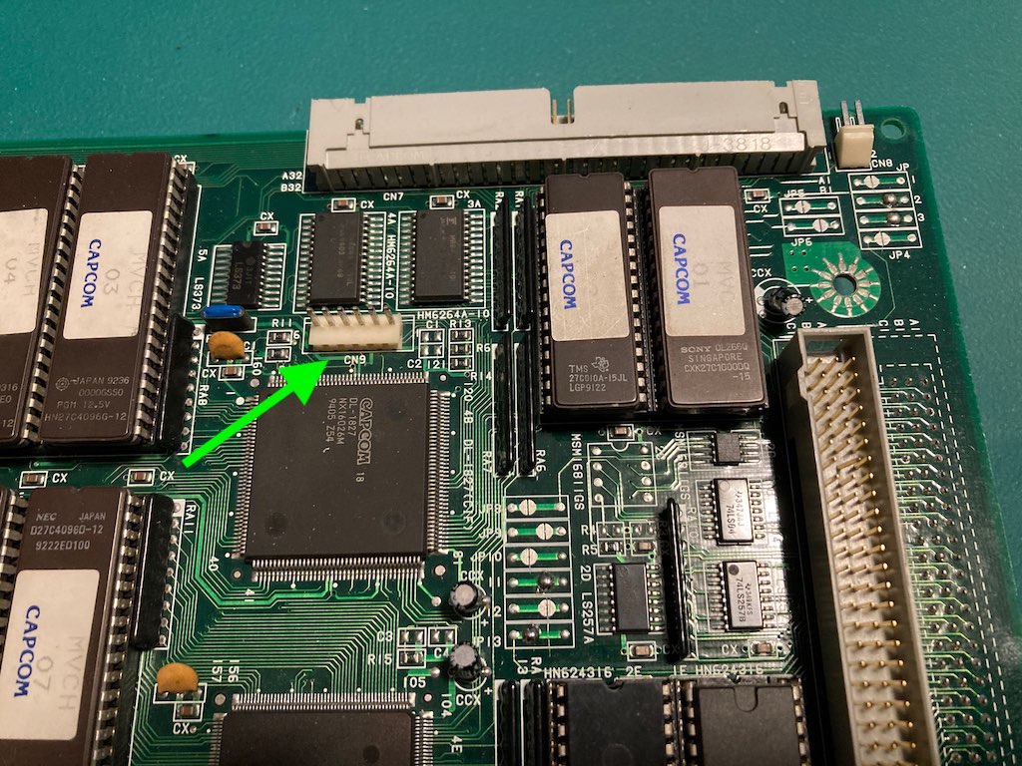
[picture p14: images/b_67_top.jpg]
b-5 top


Bottom:
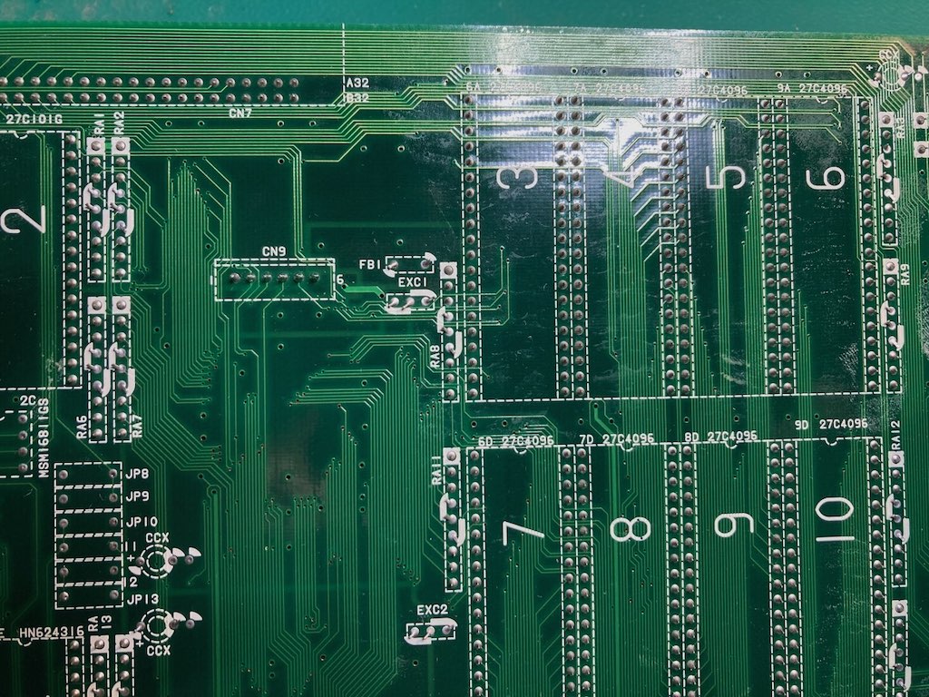
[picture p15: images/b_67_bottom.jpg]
b-5 bottom


Solder the castellated holes on CN9 of openkey-cps2 to the underside pins for CN9 on the CPS2 PCB.  Additionally solder a wire going from the +5V pad on the openkey-cps2 to RA2 pin 1 as seen below.  Then jumper 1 to 8 based on which game you need.  

Installed:
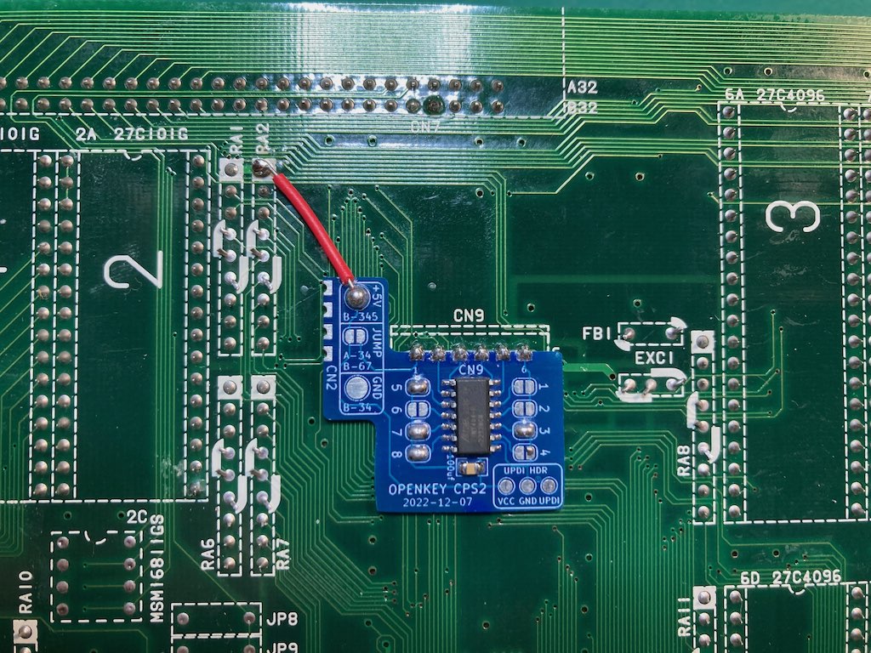
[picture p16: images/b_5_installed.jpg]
b-5 installed


### **93646B-6**
### **93646B-7**
---
93646B-6 and 93646B-7 have the same install process.

Identify CN9 on the top side of the CPS2 B Board PCB.  The underside of CN9 is what we will be installing openkey-cps2 to.

Top:
b-67 top

Bottom:
b-67 bottom

Solder the castellated holes on CN9 of openkey-cps2 to the underside pins for CN9 on the CPS2 PCB.  Additionally jumper the **JUMP** pad as pointed out by the green arrow in the picture below.  Then jumper 1 to 8 based on which game you need.  

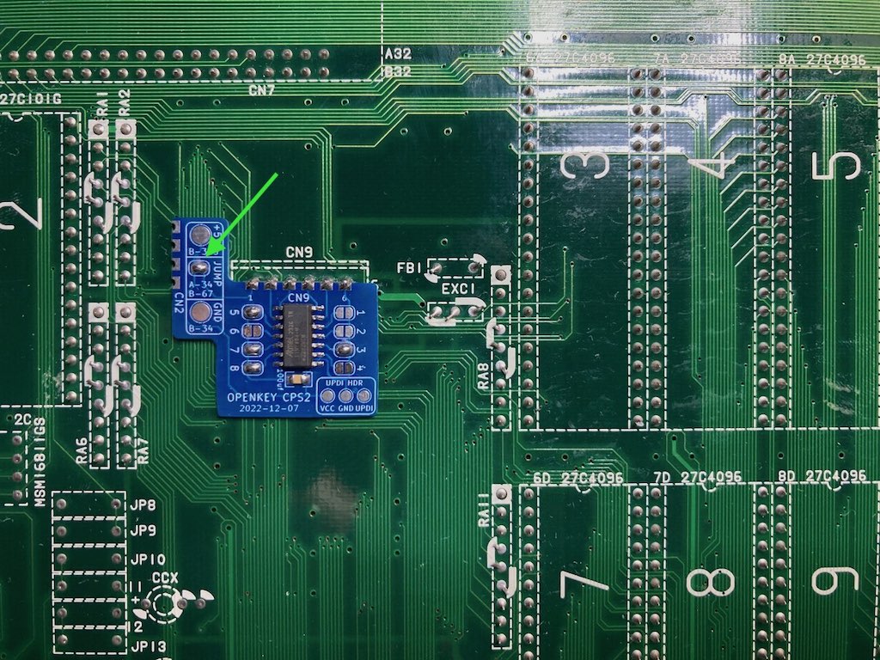
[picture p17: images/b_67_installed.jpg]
b-67 installed
Installed

### **97691A-3 (all in one)**
### **97691A-4 (all in one)**
---
97691A-3 and 97691A-4 have the same install process.

Identify CN1 on the top side of the CPS2 PCB.  It should be next to the memory socket in the corner.  The underside of CN1 is what we will be installing openkey-cps2 to.

Top:
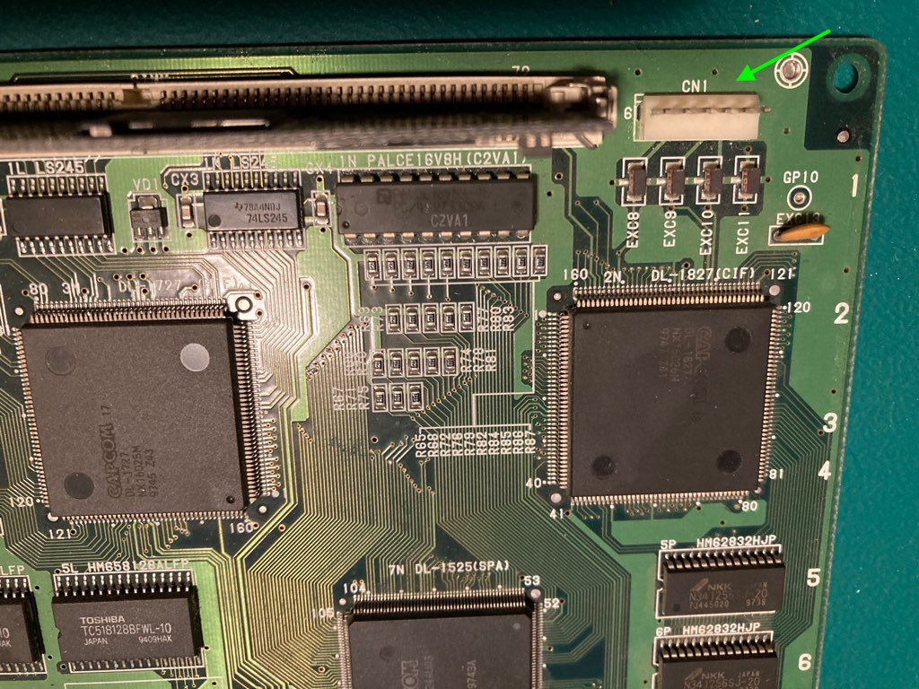
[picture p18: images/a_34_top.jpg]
a-34 top


Bottom:
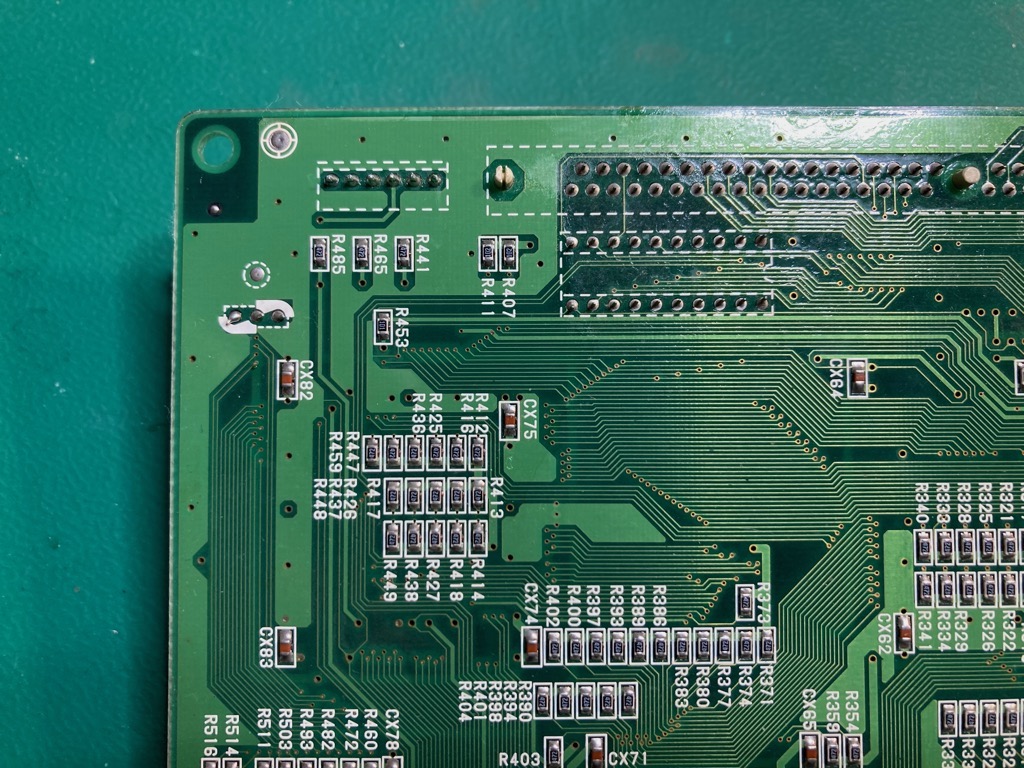
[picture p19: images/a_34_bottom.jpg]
a-34 bottom


openkey-cps2 will sit on top of those 4 resistors seen in the above picture.  Solder the castellated holes on CN9 of openkey-cps2 to the underside pins for CN1 on the CPS2 PCB.  Additionally jumper the **JUMP** pad as pointed out by the green arrow in the picture below.  Then jumper 1 to 8 based on which game you need.  

Installed:
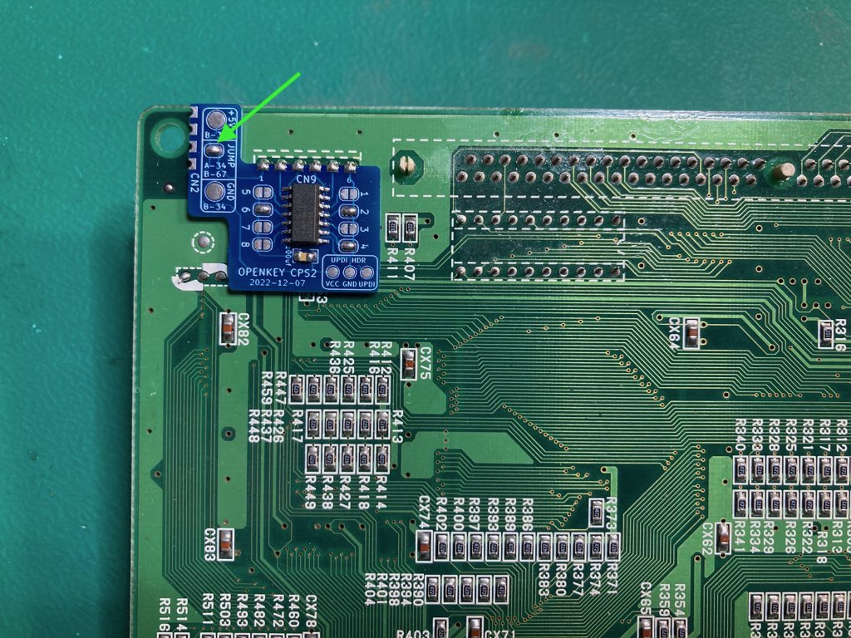
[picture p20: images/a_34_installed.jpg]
a-34 installed


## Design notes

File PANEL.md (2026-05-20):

# Panel Details
The panel version of openkey-cps2 contains 9 boards and is setup to allow
the board manufacture to assemble them.  I've only had jlcpcb do the assembly,
the below instructions may or may not work with other pcb manufactures.

panel

**IMPORTANT:** Make sure you are logged into your jlcpcb account before trying
to upload the panel to their instant quote page.  They often seem to stop
processing uploaded gerber files and give up if you aren't logged in.

Goto https://github.com/jwestfall69/openkey-cps2/releases/tag/hw-rev-2023-01-03
and grab `openkey-cps2-panel-hw-rev-2023-01-03-updated.zip`

If you are only wanting the PCBs, upload openkey-cps2-panel.zip (gerbers)
file that is within the downloaded panel release zip file to jlcpcb's quote
page.  Then continue on.

**IMPORTANT:** This will get you the assembled boards, but you must still
program them (and hopefully test them).

### Quote Page
This is the normal quote page for jlcpcb.  Upload openkey-cps2-panel.zip
(gerbers) file that is within the downloaded panel release zip, then set the
following settings as seen in the pictures below

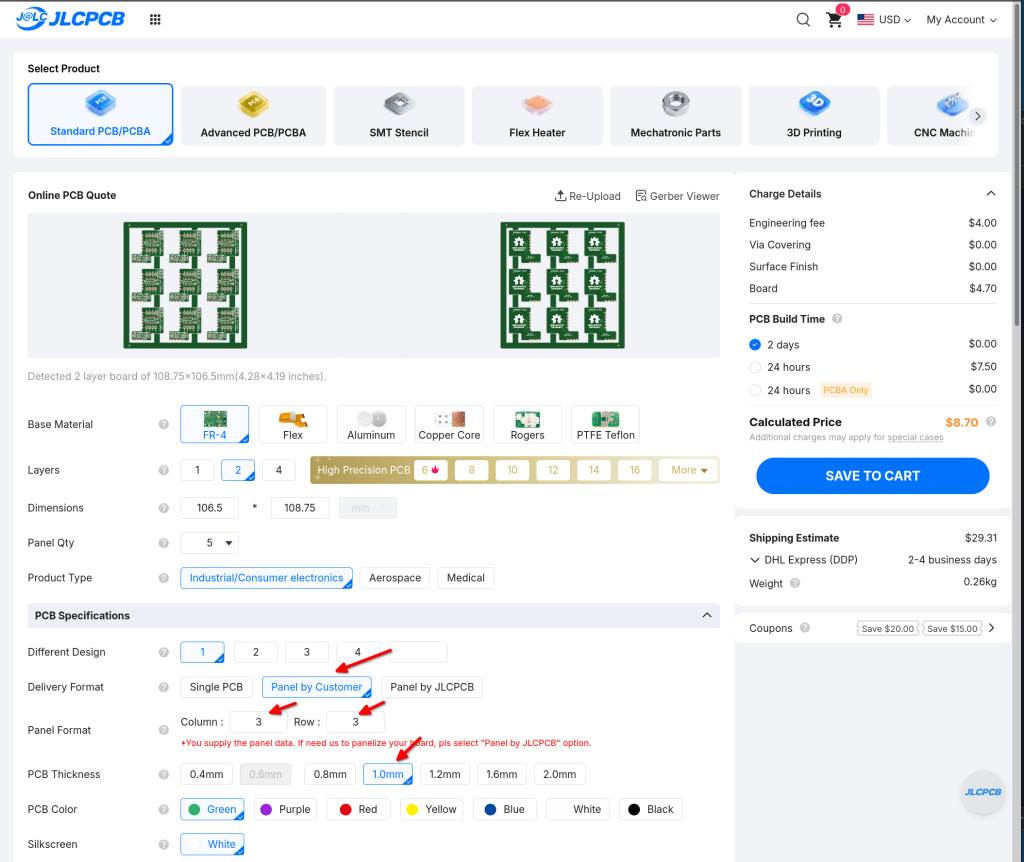
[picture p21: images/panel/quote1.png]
quote1

* Set Delivery Format to `Panel by Customer`
* Set Panel Format to Column: 3 and Row: 3
* Set PCB Thickness to 1.0mm (or leave at the default of 1.6mm if you prefer)
* Pick whatever color you want

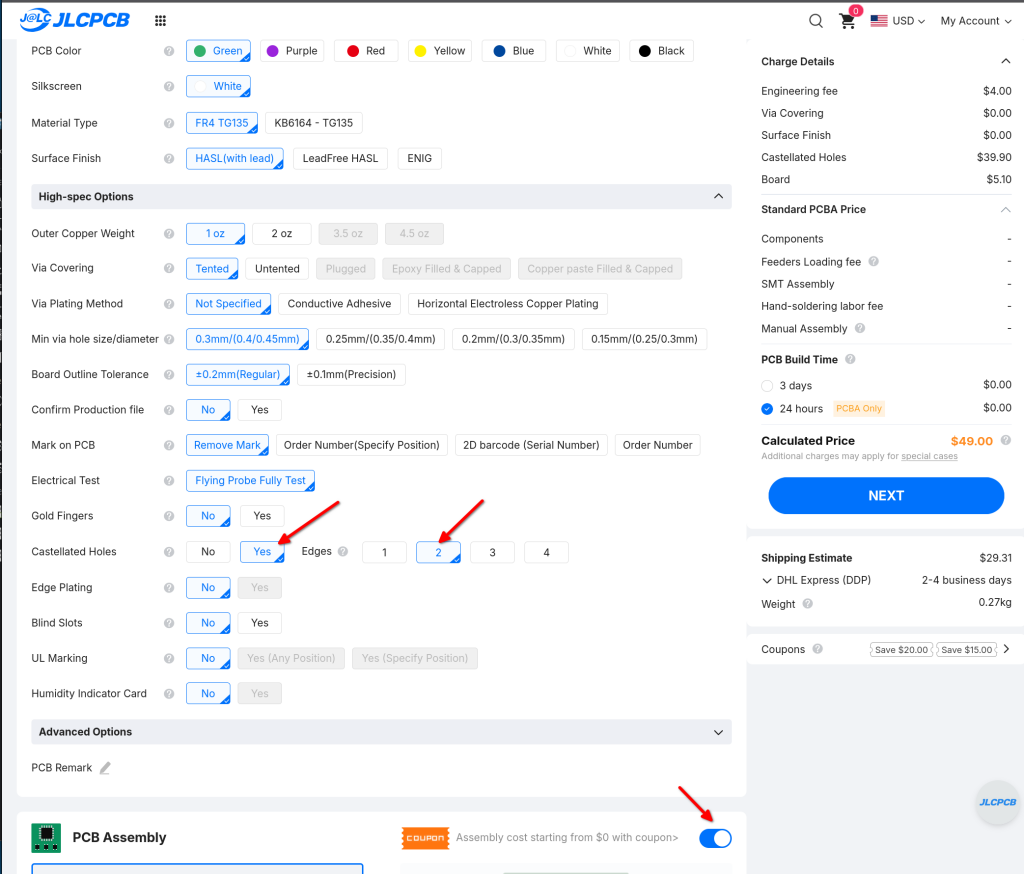
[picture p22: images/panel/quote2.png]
quote2

* Set Castellated Holes to YES with 2 sides
* Enable PCB Assembly

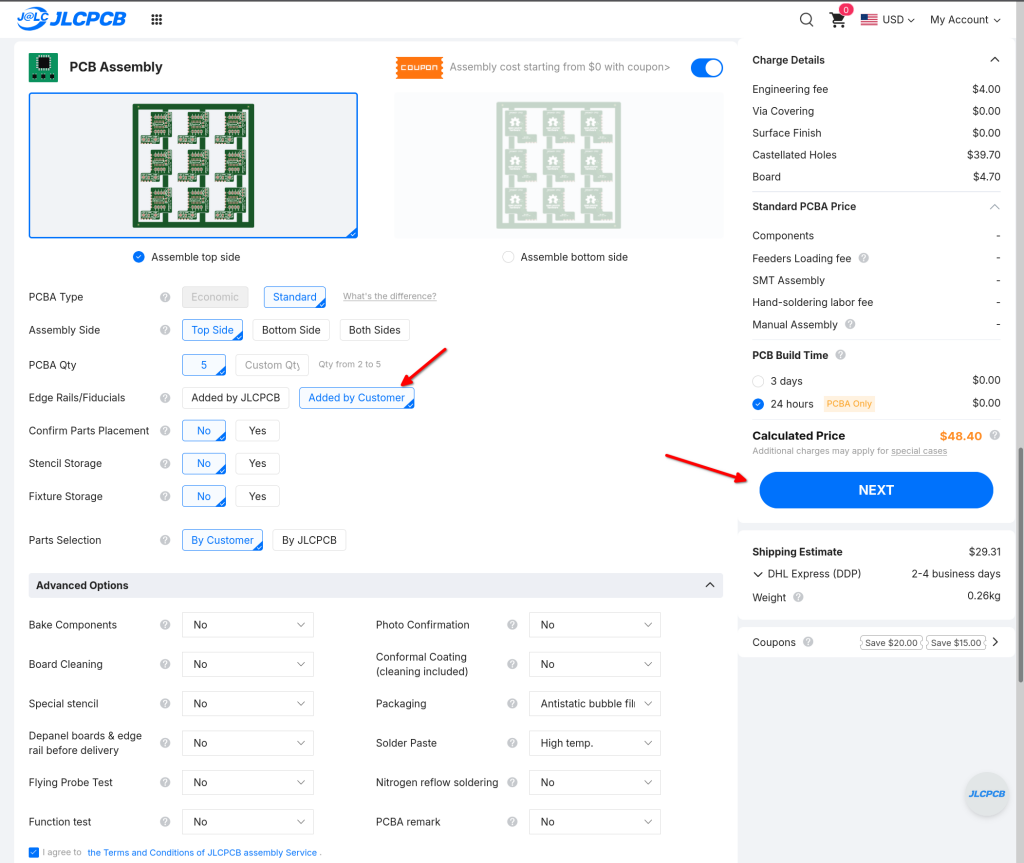
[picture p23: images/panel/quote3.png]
quote3

* Set Edge Rails/Fiducials to `Added by Customer`
* Click NEXT

### PCB
The next page just shows an image of the PCB, click NEXT again
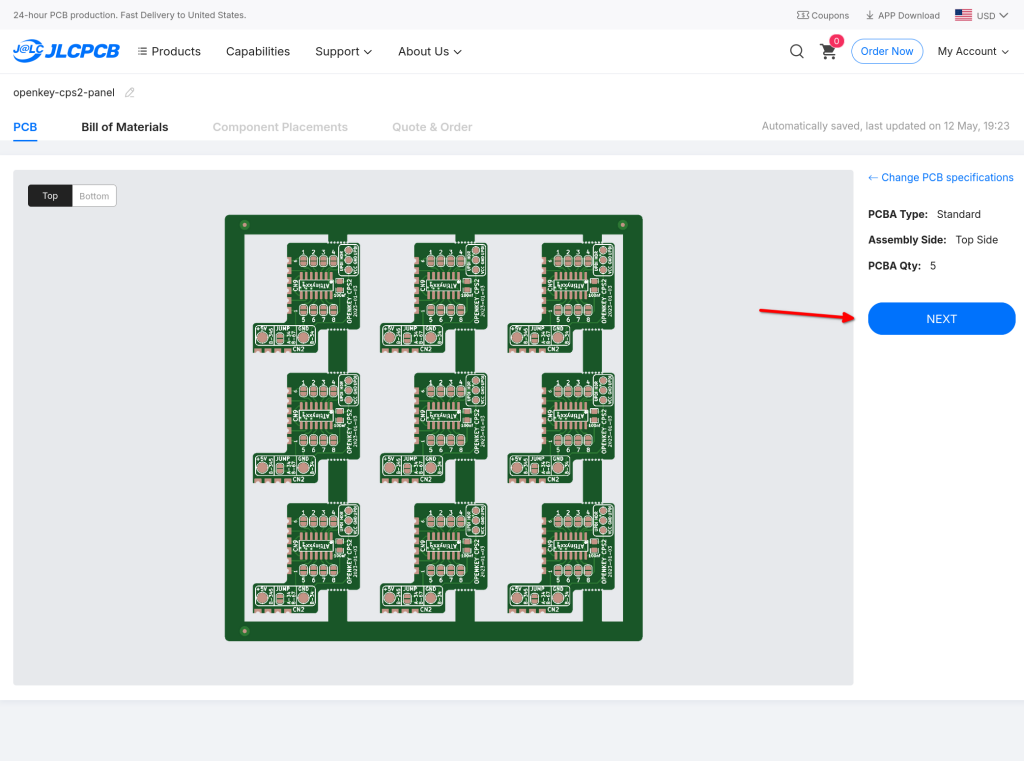
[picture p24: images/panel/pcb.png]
pcb


### BOM + Position Files
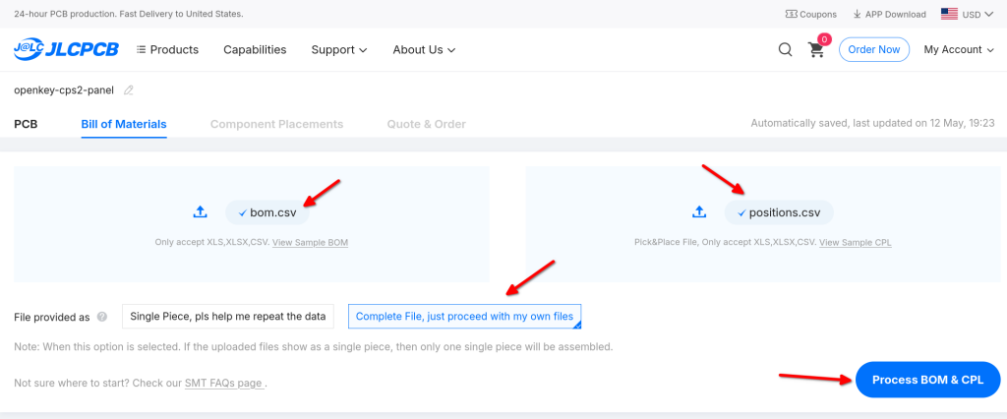
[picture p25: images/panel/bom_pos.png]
bom_pos

* Upload bom.csv from the panel release zip
* Upload positions.csv from the panel release zip
* Set File provided as to `Complete File, just proceed with my own files`
* Click Process BOM & CPL

Expect to get the following error when clicking, just click continue.  Kikit is
used to generate the panel PCB from the single board PCB.  Its fiducials are
getting auto added to the positions.csv file by the jlcpcb fabrication exports plugin.
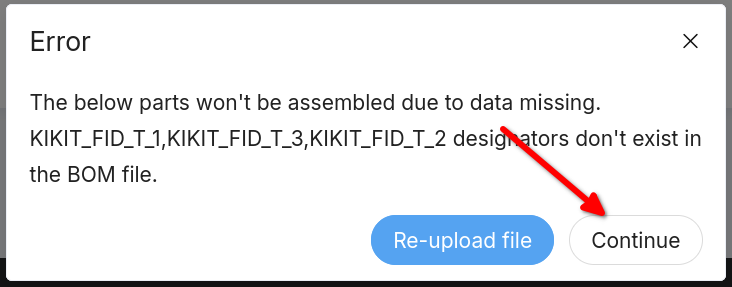
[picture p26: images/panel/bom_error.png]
bom_error


### Parts
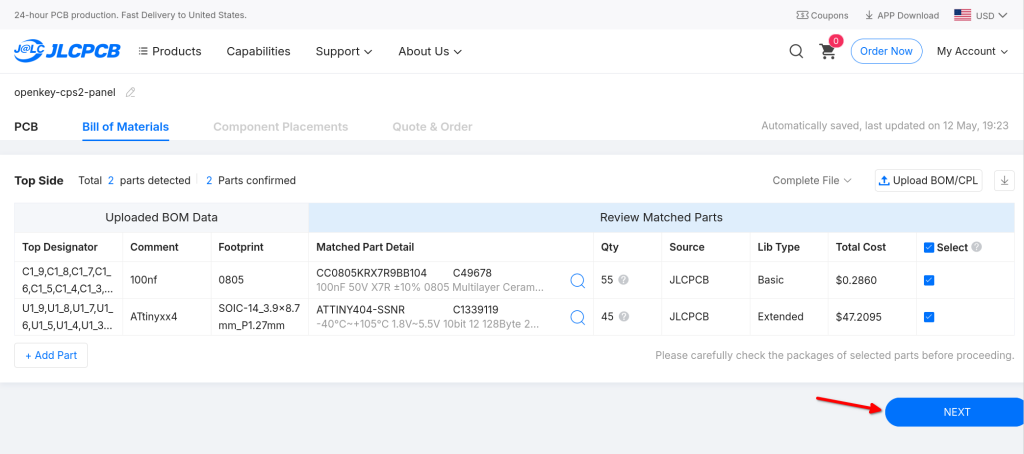
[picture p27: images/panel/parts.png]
parts

This page is showing the parts needed for assembly.  The jlcpcb's LCSC part
numbers are provide in the bom.csv, so they should be able to figure out the
parts from their inventory.  Its just 9x 100uf and 9x ATtiny404s per panel.

Its not clear to me why they over quantity the 100uf, but they are super cheap.
In the above picture its $0.28 for 55 of them.

NOTE: when I placed my test order there were only 270 ATtiny404s in stock.  I'm
not sure what jlcpcb does if there isn't enough inventory.

### Parts Placement
The next screen will show you where jlcpcb thinks the components should be
placed on the panel. 

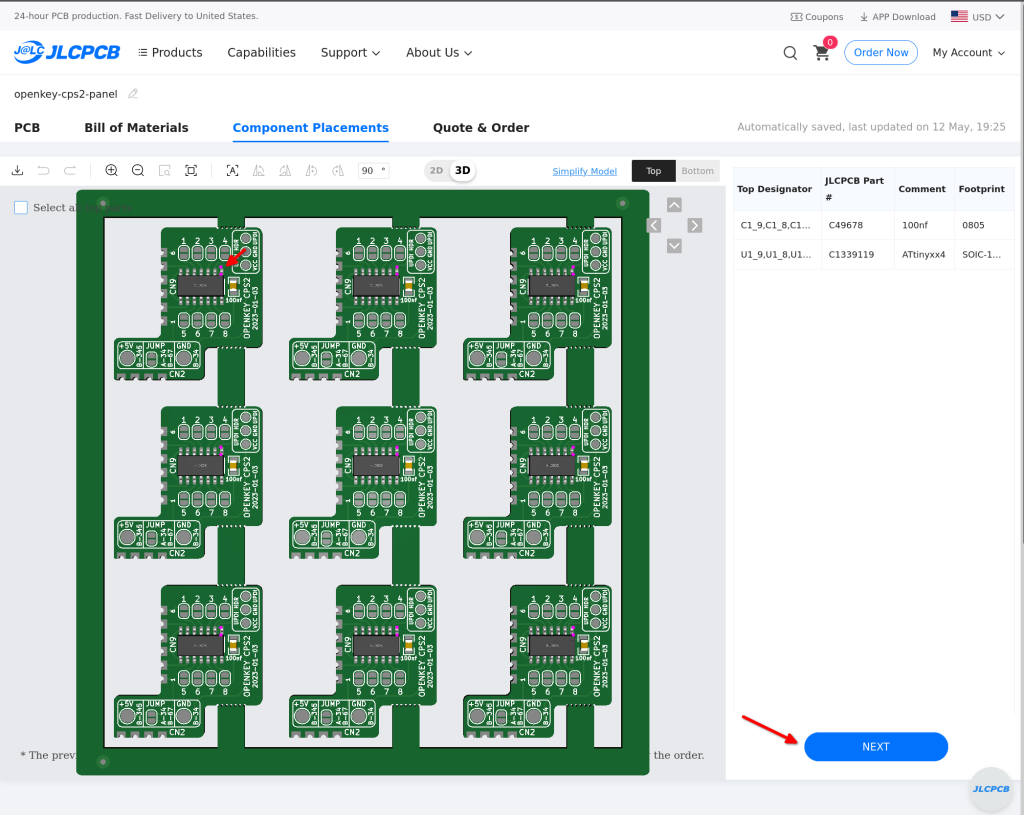
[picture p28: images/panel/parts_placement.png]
parts_placement


Make sure the parts are in the proper locations and that pin 1 (pinkish dots)
for each board in the panel is in the upper right as pointed out by the red
arrow.  If that looks good click NEXT

### Save to Cart
The last page goes over the cost totals, if those look good click save to cart
and then checkout.
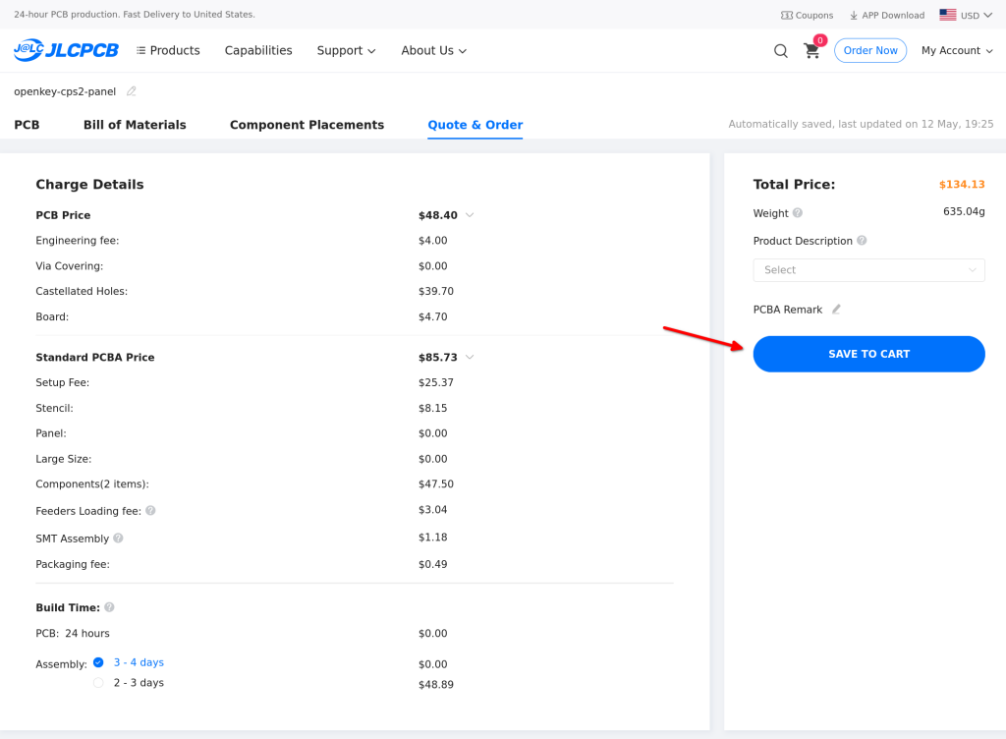
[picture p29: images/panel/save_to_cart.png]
save_to_cart


## Generating A new panel
Notes if you want to generate a new panel from the original pcb.  You will need
to install [kikit](https://github.com/yaqwsx/KiKit) and the associated kikit
plugin/library in kicad (Tools->Plugin And Content Manger) then Plugins->kikit
and Libraries->kikit.

From the command line goto to hardware directory of the openkey-cps2 project and
create a new directory like `panel-test`.  Then running the following command to
generate the panel version.

```
jwestfall@bazzite:~/openkey-cps2/hardware$ kikit panelize -p kikit-openkey-cps2-panel.json openkey-cps2.kicad_pcb panel-test/openkey-cps2-panel.kicad_pcb
```

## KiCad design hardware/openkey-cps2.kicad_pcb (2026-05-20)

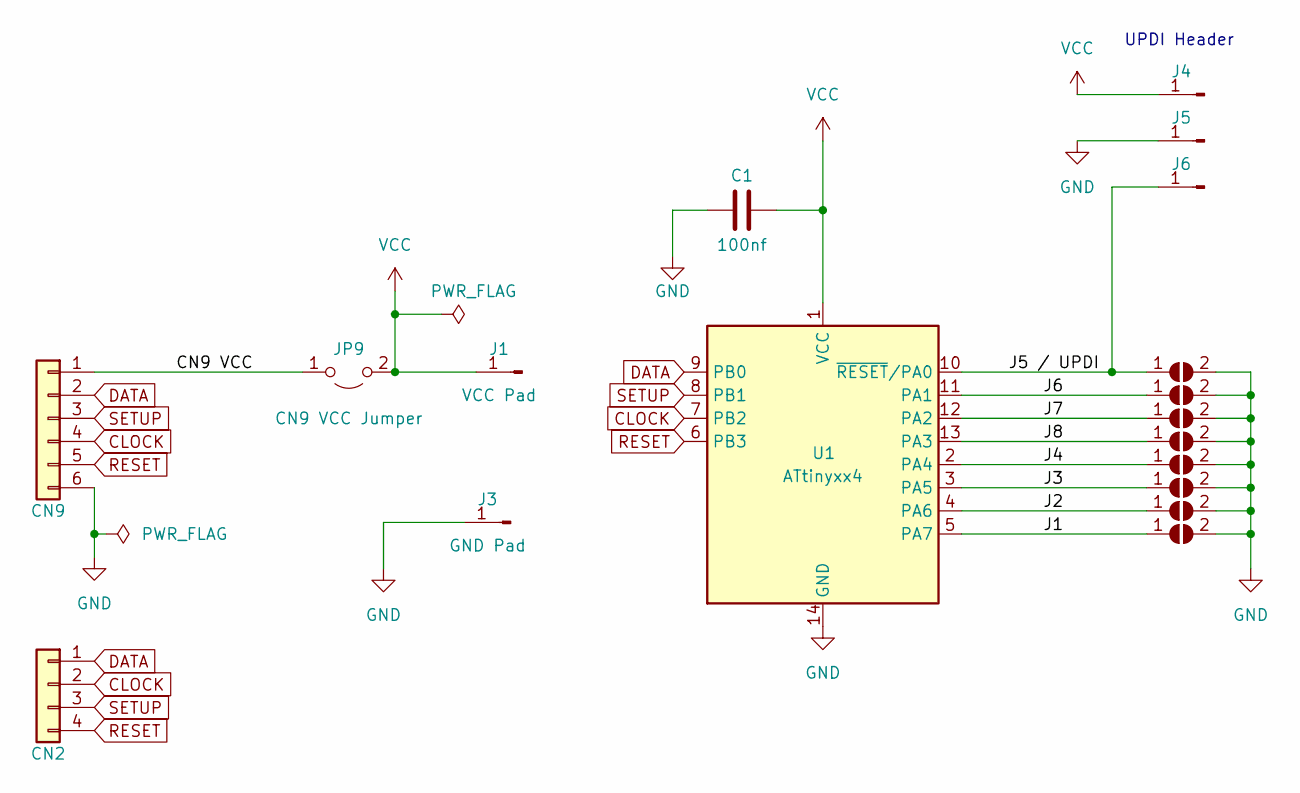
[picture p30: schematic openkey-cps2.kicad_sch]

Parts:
C1: 100nf; C_0805_2012Metric_Pad1.18x1.45mm_HandSolder; LCSC C49678
CN9: Conn_01x06; PinHeader_1x06_P2.54mm_Vertical
J1: VCC Pad; TestPoint_Pad_D2.5mm
J2: CN2; PinHeader_1x04_P2.54mm_Vertical
J3: GND Pad; TestPoint_Pad_D2.5mm
J4: VCC; TestPoint_Pad_D1.5mm
J5: GND; TestPoint_Pad_D1.5mm
J6: J5 / UDPI; TestPoint_Pad_D1.5mm
JP1, JP2, JP3, JP4, JP5, JP6, JP7, JP8: SolderJumper_2_Open; SolderJumper-2_P1.3mm_Open_RoundedPad1.0x1.5mm
JP9: CN9 VCC Jumper; SolderJumper-2_P1.3mm_Open_RoundedPad1.0x1.5mm
U1: ATtinyxx4; SOIC-14_3.9x8.7mm_P1.27mm; LCSC C1339119

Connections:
/CN9 VCC: CN9.1, JP9.1 (A)
/J1: JP8.1 (A), U1.5 (PA7)
/J2: JP7.1 (A), U1.4 (PA6)
/J3: JP6.1 (A), U1.3 (PA5)
/J4: JP5.1 (A), U1.2 (PA4)
/J5 / UPDI: J6.1 (Pin_1_1), JP1.1 (A), U1.10 (~RESET/PA0)
/J6: JP2.1 (A), U1.11 (PA1)
/J7: JP3.1 (A), U1.12 (PA2)
/J8: JP4.1 (A), U1.13 (PA3)
CLOCK: CN9.4, J2.2, U1.7 (PB2)
DATA: CN9.2, J2.1, U1.9 (PB0)
GND: C1.1, CN9.6, J3.1 (Pin_1_1), J5.1 (Pin_1_1), JP1.2 (B), JP2.2 (B), JP3.2 (B), JP4.2 (B), JP5.2 (B), JP6.2 (B), JP7.2 (B), JP8.2 (B), U1.14 (GND)
RESET: CN9.5, J2.4, U1.6 (PB3)
SETUP: CN9.3, J2.3, U1.8 (PB1)
VCC: C1.2, J1.1 (Pin_1_1), J4.1 (Pin_1_1), JP9.2 (B), U1.1 (VCC)

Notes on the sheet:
UPDI Header

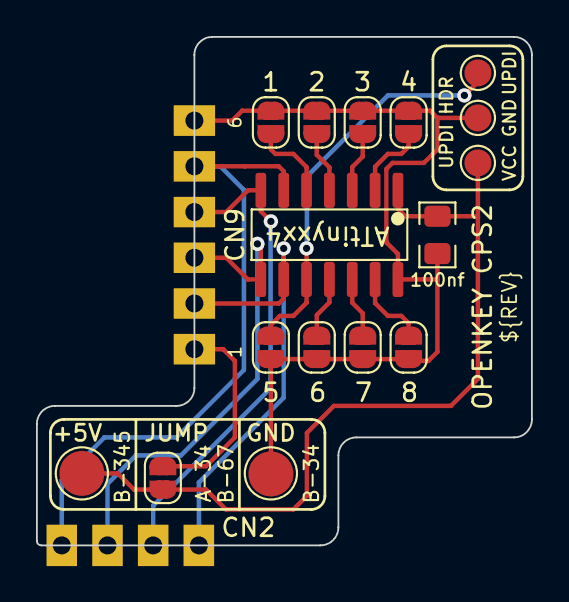
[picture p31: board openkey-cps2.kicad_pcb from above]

Board: 2 copper layers, 27.5 x 28.2 mm, 18 parts (0 on the bottom side), 15 nets.

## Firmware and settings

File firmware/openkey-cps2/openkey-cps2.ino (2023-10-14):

#include <avr/sleep.h>

// PIN 9 (PIN_B1) <=> CN9 PIN 2
#define SET_DATA      PORTB.OUTSET = PIN0_bm
#define CLR_DATA      PORTB.OUTCLR = PIN0_bm

// PIN 8 (PIN_B0) <=> CN9 PIN 3
#define SET_SETUP    PORTB.OUTSET = PIN1_bm
#define CLR_SETUP    PORTB.OUTCLR = PIN1_bm

// PIN 6 (PIN_B3) <=> CN9 PIN 4
#define SET_RESET     PORTB.OUTSET = PIN3_bm
#define CLR_RESET     PORTB.OUTCLR = PIN3_bm

// PIN 7 (PIN_B2) <=> CN9 PIN 5
#define SET_CLOCK     PORTB.OUTSET = PIN2_bm
#define CLR_CLOCK     PORTB.OUTCLR = PIN2_bm

// doing bit shifting takes a variable amount
// of time depending on the how far the shift
// is.  Using the below lookup table to try
// and keep a consistent clock period when
// sending data.
uint8_t masks[8] = {
  0x01, 0x02, 0x04, 0x08,
  0x10, 0x20, 0x40, 0x80,
};

// The key data below comes from mame.  Each game has a .key file, which contains the 20 bytes.
// ie: https://github.com/mamedev/mame/blob/master/src/mame/capcom/cps2.cpp#L1900
#define CONFIG_SIZE   6
#define WATCHDOG_SIZE 6
#define KEY_SIZE      4

// There are only 10 unique combinations of the first 6 bytes
// of all key data.  In order to save about 800 bytes of flash
// we are using the below lookup table for these 6 bytes. 
// Without the lookup table the code compiles very near to 4k,
// which would put it at risk of not being viable on attiny4x4s
uint8_t config_table[][CONFIG_SIZE] = {
 { 0x01, 0x00, 0x02, 0x40, 0x00, 0x08 },  // 0x00
 { 0x01, 0x00, 0x02, 0x40, 0x00, 0x09 },  // 0x01
 { 0x01, 0x00, 0x02, 0x40, 0x00, 0x0a },  // 0x02
 { 0x07, 0x00, 0x02, 0x40, 0x00, 0x08 },  // 0x03
 { 0x07, 0x00, 0x02, 0x40, 0x00, 0x0a },  // 0x04
 { 0x0f, 0x00, 0x02, 0x40, 0x00, 0x08 },  // 0x05
 { 0x0f, 0x00, 0x02, 0x40, 0x00, 0x09 },  // 0x06
 { 0x0f, 0x00, 0x02, 0x40, 0x00, 0x0a },  // 0x07
 { 0x3f, 0x00, 0x02, 0x40, 0x00, 0x08 },  // 0x08
 { 0xff, 0xff, 0xff, 0xff, 0xff, 0xff },  // 0x09
};

struct game_data_t {
  uint8_t config_table_index;
  uint8_t watchdog[WATCHDOG_SIZE];
  uint8_t key2[KEY_SIZE];
  uint8_t key1[KEY_SIZE];
};

#define MAX_GAME_NUM 174
struct game_data_t game_data[MAX_GAME_NUM + 1] = {
  // config table                                                                                                          jumpers
  //    index                  watchdog config                         key#2                        key#1                  12345678 raw key filename
  {     0x06,       { 0x84, 0xc2, 0xeb, 0x7a, 0x3c, 0xa5 },  { 0xf4, 0x38, 0xeb, 0x65 },  { 0x79, 0x9c, 0xbf, 0x70 } }, // 00000000 1944.key
  {     0x06,       { 0x84, 0xc2, 0xeb, 0x7a, 0x3c, 0xa5 },  { 0x8b, 0x93, 0x46, 0x1d },  { 0x70, 0xe7, 0xaf, 0x10 } }, // 00000001 1944j.key
  {     0x06,       { 0x84, 0xc2, 0xeb, 0x7a, 0x3c, 0xa5 },  { 0x78, 0xfe, 0x6b, 0x44 },  { 0xc9, 0x39, 0xf2, 0xe0 } }, // 00000010 1944u.key
  {     0x04,       { 0x04, 0xc2, 0xa4, 0x02, 0x02, 0x21 },  { 0xe8, 0x85, 0x13, 0x2a },  { 0x2e, 0x46, 0x8b, 0x00 } }, // 00000011 19xx.key
  {     0x04,       { 0x04, 0xc2, 0xa4, 0x02, 0x02, 0x22 },  { 0x23, 0xb1, 0x6f, 0xb6 },  { 0xbc, 0xcb, 0x9c, 0xcc } }, // 00000100 19xxa.key
  {     0x04,       { 0x04, 0xc2, 0xa4, 0x02, 0x02, 0x23 },  { 0xf1, 0x1b, 0x7e, 0xd1 },  { 0x5b, 0x8a, 0x7e, 0x9c } }, // 00000101 19xxb.key
  {     0x04,       { 0x04, 0xc2, 0xa4, 0x02, 0x02, 0x23 },  { 0xe4, 0xda, 0x13, 0xbd },  { 0x7d, 0x76, 0x4a, 0xe8 } }, // 00000110 19xxh.key
  {     0x04,       { 0x04, 0xc2, 0xa4, 0x02, 0x02, 0x21 },  { 0xf8, 0x7f, 0xc0, 0x00 },  { 0x7e, 0xea, 0x20, 0x00 } }, // 00000111 19xxj.key
  {     0x04,       { 0x04, 0xc2, 0xa4, 0x02, 0x02, 0x20 },  { 0x04, 0x3c, 0x2f, 0xeb },  { 0xe0, 0x63, 0x81, 0xc0 } }, // 00001000 19xxu.key
  {     0x07,       { 0x70, 0x30, 0x04, 0x00, 0x10, 0x0b },  { 0xe0, 0x42, 0x71, 0x47 },  { 0x40, 0xca, 0xe5, 0xe4 } }, // 00001001 armwar.key
  {     0x07,       { 0x70, 0x30, 0x04, 0x00, 0x10, 0x08 },  { 0x42, 0x71, 0x47, 0x40 },  { 0xca, 0xe5, 0xe7, 0xe0 } }, // 00001010 armwara.key
  {     0x07,       { 0x70, 0x30, 0x04, 0x00, 0x10, 0x0a },  { 0x04, 0x27, 0x14, 0x74 },  { 0x0c, 0xae, 0x5e, 0x7c } }, // 00001011 armwarb.key
  {     0x07,       { 0x70, 0x30, 0x04, 0x00, 0x10, 0x0a },  { 0x5e, 0x7e, 0x04, 0x27 },  { 0x14, 0x74, 0x0c, 0xac } }, // 00001100 armwaru.key
  {     0x05,       { 0x04, 0xc0, 0xb1, 0x20, 0x79, 0xab },  { 0x34, 0xd9, 0xed, 0x4a },  { 0x7b, 0xc4, 0x12, 0xa0 } }, // 00001101 avsp.key
  {     0x05,       { 0x04, 0xc0, 0xb1, 0x20, 0x79, 0xa8 },  { 0x3a, 0x69, 0x49, 0xd2 },  { 0xf7, 0x3c, 0x5a, 0x0c } }, // 00001110 avspa.key
  {     0x05,       { 0x04, 0xc0, 0xb1, 0x20, 0x79, 0xab },  { 0xe9, 0xc6, 0xcf, 0x09 },  { 0x42, 0x5b, 0x52, 0x38 } }, // 00001111 avsph.key
  {     0x05,       { 0x04, 0xc0, 0xb1, 0x20, 0x79, 0xa8 },  { 0x98, 0x13, 0xb2, 0x29 },  { 0x7c, 0x74, 0xee, 0x5c } }, // 00010000 avspj.key
  {     0x05,       { 0x04, 0xc0, 0xb1, 0x20, 0x79, 0xab },  { 0x11, 0x6b, 0xbc, 0xce },  { 0x44, 0x21, 0xbc, 0xb4 } }, // 00010001 avspu.key
  {     0x04,       { 0x04, 0xc3, 0xa4, 0x02, 0x32, 0x02 },  { 0xb5, 0x1c, 0xf4, 0xf3 },  { 0xa6, 0x9e, 0xa6, 0x2c } }, // 00010010 batcir.key
  {     0x04,       { 0x04, 0xc3, 0xa4, 0x02, 0x32, 0x03 },  { 0x8d, 0xd0, 0x44, 0x67 },  { 0x4c, 0x06, 0xe9, 0xe0 } }, // 00010011 batcira.key
  {     0x04,       { 0x04, 0xc3, 0xa4, 0x02, 0x32, 0x00 },  { 0x5c, 0x40, 0x00, 0x00 },  { 0x6e, 0xcb, 0xfc, 0x00 } }, // 00010100 batcirj.key
  {     0x01,       { 0x84, 0xc3, 0xa2, 0xc8, 0xf3, 0x6a },  { 0xb7, 0xa1, 0xc7, 0xf9 },  { 0x8d, 0x23, 0x7f, 0x2c } }, // 00010101 choko.key
  {     0x04,       { 0x04, 0xc3, 0xa4, 0x00, 0x23, 0x02 },  { 0x0f, 0x9c, 0x21, 0x08 },  { 0x17, 0xe5, 0xd1, 0x98 } }, // 00010110 csclub.key
  {     0x04,       { 0x04, 0xc3, 0xa4, 0x00, 0x23, 0x03 },  { 0xb2, 0x50, 0xb5, 0x65 },  { 0x51, 0xed, 0x9b, 0x20 } }, // 00010111 cscluba.key
  {     0x04,       { 0x04, 0xc3, 0xa4, 0x00, 0x23, 0x00 },  { 0x2c, 0xa7, 0xb9, 0xd3 },  { 0x94, 0x54, 0xa0, 0x3c } }, // 00011000 csclubh.key
  {     0x04,       { 0x04, 0xc3, 0xa4, 0x00, 0x23, 0x00 },  { 0x0f, 0x20, 0x0d, 0xaa },  { 0x9f, 0x42, 0xd1, 0x48 } }, // 00011001 csclubj.key
  {     0x05,       { 0x70, 0xc3, 0xfc, 0x00, 0x70, 0xc2 },  { 0x02, 0x42, 0x42, 0x83 },  { 0x0a, 0x69, 0x0a, 0x88 } }, // 00011010 cybots.key
  {     0x05,       { 0x70, 0xc3, 0xfc, 0x00, 0x70, 0xc3 },  { 0x0a, 0x69, 0x09, 0x4a },  { 0x02, 0x42, 0x42, 0x80 } }, // 00011011 cybotsj.key
  {     0x05,       { 0x70, 0xc3, 0xfc, 0x00, 0x70, 0xc2 },  { 0x69, 0x0a, 0xaa, 0x02 },  { 0x42, 0x42, 0x83, 0x08 } }, // 00011100 cybotsu.key
  {     0x07,       { 0x04, 0xc1, 0x9a, 0x62, 0x60, 0x83 },  { 0x1b, 0xeb, 0xe0, 0x6c },  { 0xf5, 0x64, 0x47, 0x84 } }, // 00011101 ddsom.key
  {     0x07,       { 0x04, 0xc1, 0x9a, 0x62, 0x60, 0x82 },  { 0x8b, 0x05, 0x03, 0xde },  { 0xcf, 0x56, 0x63, 0x84 } }, // 00011110 ddsoma.key
  {     0x07,       { 0x04, 0xc1, 0x9a, 0x62, 0x60, 0x81 },  { 0xcf, 0xf6, 0x97, 0x3d },  { 0x07, 0x96, 0x4a, 0x38 } }, // 00011111 ddsomb.key
  {     0x07,       { 0x04, 0xc1, 0x9a, 0x62, 0x60, 0x83 },  { 0x81, 0x9e, 0xc1, 0x22 },  { 0x89, 0x0b, 0x21, 0x08 } }, // 00100000 ddsomh.key
  {     0x07,       { 0x04, 0xc1, 0x9a, 0x62, 0x60, 0x82 },  { 0x88, 0x25, 0x6a, 0x30 },  { 0xa5, 0x7d, 0x25, 0xd4 } }, // 00100001 ddsomj.key
  {     0x07,       { 0x04, 0xc1, 0x9a, 0x62, 0x60, 0x81 },  { 0x79, 0xf2, 0xcf, 0x61 },  { 0x92, 0x83, 0xe4, 0x48 } }, // 00100010 ddsomu.key
  {     0x03,       { 0x78, 0xc2, 0x60, 0x20, 0x00, 0x0a },  { 0x6e, 0xb1, 0x4c, 0xa0 },  { 0x41, 0xff, 0x9b, 0x88 } }, // 00100011 ddtod.key
  {     0x03,       { 0x78, 0xc2, 0x60, 0x20, 0x00, 0x0a },  { 0x20, 0x82, 0x3a, 0x62 },  { 0x82, 0x0d, 0x4d, 0xec } }, // 00100100 ddtoda.key
  {     0x03,       { 0x78, 0xc2, 0x60, 0x20, 0x00, 0x08 },  { 0x1e, 0xee, 0x90, 0x5e },  { 0x60, 0x22, 0x5a, 0x60 } }, // 00100101 ddtodh.key
  {     0x03,       { 0x78, 0xc2, 0x60, 0x20, 0x00, 0x0a },  { 0xd1, 0x47, 0x5b, 0x3c },  { 0xe7, 0x9c, 0x22, 0x88 } }, // 00100110 ddtodj.key
  {     0x03,       { 0x78, 0xc2, 0x60, 0x20, 0x00, 0x08 },  { 0x3f, 0x5b, 0x38, 0x92 },  { 0xf0, 0xe6, 0x14, 0xdc } }, // 00100111 ddtodu.key
  {     0x05,       { 0xc9, 0xf4, 0x89, 0x36, 0x8d, 0xb7 },  { 0x52, 0xff, 0xa0, 0x50 },  { 0x09, 0xc7, 0x6e, 0xc0 } }, // 00101000 dimahoo.key
  {     0x05,       { 0xc9, 0xf4, 0x89, 0x36, 0x8d, 0xb6 },  { 0x25, 0x95, 0xfc, 0x36 },  { 0x6b, 0xd6, 0xba, 0x98 } }, // 00101001 dimahoou.key
  {     0x05,       { 0x70, 0x40, 0x00, 0x00, 0x1a, 0x18 },  { 0x24, 0x34, 0x40, 0x00 },  { 0x57, 0x94, 0x6f, 0x20 } }, // 00101010 dstlk.key
  {     0x05,       { 0x70, 0x40, 0x00, 0x00, 0x1a, 0x1a },  { 0x3a, 0x61, 0x11, 0x80 },  { 0x67, 0x06, 0xe8, 0x10 } }, // 00101011 dstlka.key
  {     0x05,       { 0x70, 0x40, 0x00, 0x00, 0x1a, 0x19 },  { 0x56, 0x5a, 0x22, 0x01 },  { 0xfd, 0xf1, 0x89, 0x10 } }, // 00101100 dstlkh.key
  {     0x05,       { 0x70, 0x40, 0x00, 0x00, 0x1a, 0x1a },  { 0x62, 0x39, 0x10, 0x20 },  { 0x3f, 0x5c, 0x05, 0xe0 } }, // 00101101 dstlku.key
  {     0x03,       { 0x70, 0x43, 0x00, 0x02, 0x8b, 0x38 },  { 0xa9, 0xb8, 0x65, 0x74 },  { 0xee, 0x30, 0x23, 0x24 } }, // 00101110 ecofghtr.key
  {     0x03,       { 0x70, 0x43, 0x00, 0x02, 0x8b, 0x39 },  { 0x30, 0xa9, 0xb8, 0x65 },  { 0x76, 0x30, 0x23, 0x24 } }, // 00101111 ecofghtra.key
  {     0x03,       { 0x70, 0x43, 0x00, 0x02, 0x8b, 0x3b },  { 0x0a, 0x9b, 0x86, 0x57 },  { 0x4e, 0x30, 0x23, 0x24 } }, // 00110000 ecofghtrh.key
  {     0x03,       { 0x70, 0x43, 0x00, 0x02, 0x8b, 0x3a },  { 0x9b, 0x86, 0x57, 0x4e },  { 0xde, 0x30, 0x23, 0x24 } }, // 00110001 ecofghtru.key
  {     0x07,       { 0x04, 0xc1, 0x3a, 0x63, 0x90, 0x20 },  { 0x07, 0xac, 0x1b, 0x60 },  { 0x25, 0x1e, 0xd2, 0x9c } }, // 00110010 gigawing.key
  {     0x07,       { 0x04, 0xc1, 0x3a, 0x63, 0x90, 0x20 },  { 0x5b, 0xb6, 0x35, 0x99 },  { 0x68, 0x55, 0x82, 0xb0 } }, // 00110011 gigawinga.key
  {     0x07,       { 0x04, 0xc1, 0x3a, 0x63, 0x90, 0x22 },  { 0xe7, 0xfb, 0xdd, 0xa4 },  { 0x36, 0x8b, 0x9f, 0xc0 } }, // 00110100 gigawingb.key
  {     0x07,       { 0x04, 0xc1, 0x3a, 0x63, 0x90, 0x22 },  { 0x87, 0x16, 0xc0, 0x0a },  { 0x21, 0x0b, 0x95, 0xcc } }, // 00110101 gigawingh.key
  {     0x07,       { 0x04, 0xc1, 0x3a, 0x63, 0x90, 0x22 },  { 0xa4, 0x42, 0xbd, 0xf5 },  { 0x5a, 0x61, 0x92, 0x20 } }, // 00110110 gigawingj.key
  {     0x05,       { 0xc9, 0xf4, 0x89, 0x36, 0x8d, 0xb5 },  { 0x1b, 0x5e, 0x12, 0x18 },  { 0x69, 0xf7, 0xbf, 0xa4 } }, // 00110111 gmahou.key
  {     0x05,       { 0x70, 0x43, 0x80, 0x00, 0x00, 0x10 },  { 0xe4, 0x63, 0x15, 0xfe },  { 0xee, 0xe5, 0xb1, 0x68 } }, // 00111000 hsf2.key
  {     0x05,       { 0x70, 0x43, 0x80, 0x00, 0x00, 0x12 },  { 0xf1, 0x43, 0x1d, 0x54 },  { 0x31, 0xb2, 0xdc, 0x74 } }, // 00111001 hsf2a.key
  {     0x05,       { 0x70, 0x43, 0x80, 0x00, 0x00, 0x13 },  { 0x89, 0xf0, 0x77, 0x6c },  { 0x1f, 0xd0, 0x6e, 0x98 } }, // 00111010 hsf2j.key
  {     0x05,       { 0x04, 0xc1, 0x29, 0xb3, 0x3a, 0xa2 },  { 0x6b, 0xf1, 0xbd, 0x25 },  { 0x9d, 0x50, 0x94, 0xd8 } }, // 00111011 jyangoku.key
  {     0x05,       { 0x04, 0xc0, 0x9a, 0x02, 0x02, 0x38 },  { 0x2a, 0x98, 0xb2, 0xdc },  { 0xd4, 0xe0, 0x28, 0x28 } }, // 00111100 megaman2.key
  {     0x05,       { 0x04, 0xc0, 0x9a, 0x02, 0x02, 0x3a },  { 0xa1, 0x42, 0x79, 0xaf },  { 0x51, 0x44, 0xa3, 0xf0 } }, // 00111101 megaman2a.key
  {     0x05,       { 0x04, 0xc0, 0x9a, 0x02, 0x02, 0x38 },  { 0x2c, 0x21, 0x02, 0x91 },  { 0x4f, 0x3a, 0xa9, 0xb8 } }, // 00111110 megaman2h.key
  {     0x05,       { 0x04, 0xc0, 0x9a, 0x80, 0xa6, 0x12 },  { 0x92, 0x90, 0x98, 0xa5 },  { 0x7f, 0x24, 0x4a, 0x80 } }, // 00111111 mmancp2u.key
  {     0x03,       { 0x0d, 0xb7, 0x88, 0xb7, 0xcd, 0x77 },  { 0xef, 0x98, 0x82, 0x0a },  { 0x7a, 0xf5, 0xe4, 0xd4 } }, // 01000000 mmatrix.key
  {     0x03,       { 0x0d, 0xb7, 0x88, 0xb7, 0xcd, 0x75 },  { 0x8a, 0xad, 0x7a, 0x6c },  { 0xd5, 0x2b, 0xb5, 0x50 } }, // 01000001 mmatrixa.key
  {     0x03,       { 0x0d, 0xb7, 0x88, 0xb7, 0xcd, 0x77 },  { 0x10, 0x66, 0xdd, 0x3a },  { 0xa5, 0xe0, 0x7e, 0xc8 } }, // 01000010 mmatrixj.key
  {     0x05,       { 0x84, 0xc2, 0xf8, 0xb3, 0x16, 0x47 },  { 0x61, 0x17, 0x8a, 0x9d },  { 0x8e, 0x0b, 0xbe, 0xa4 } }, // 01000011 mpang.key
  {     0x07,       { 0x04, 0xc1, 0x9a, 0x62, 0x60, 0x83 },  { 0xa2, 0xea, 0xa7, 0x9d },  { 0x91, 0xde, 0x21, 0x60 } }, // 01000100 msh.key
  {     0x07,       { 0x04, 0xc1, 0x9a, 0x62, 0x60, 0x82 },  { 0xf2, 0x8f, 0xa4, 0x72 },  { 0x03, 0x5d, 0x7a, 0x88 } }, // 01000101 msha.key
  {     0x07,       { 0x04, 0xc1, 0x9a, 0x62, 0x60, 0x81 },  { 0x9c, 0x7f, 0x92, 0xd5 },  { 0xa0, 0x92, 0xa1, 0x78 } }, // 01000110 mshb.key
  {     0x07,       { 0x04, 0xc1, 0x9a, 0x62, 0x60, 0x80 },  { 0x26, 0x0c, 0xe6, 0xb4 },  { 0x29, 0x68, 0xc8, 0xfc } }, // 01000111 mshh.key
  {     0x07,       { 0x04, 0xc1, 0x9a, 0x62, 0x60, 0x81 },  { 0x0a, 0x12, 0xd6, 0x32 },  { 0x61, 0x04, 0x5e, 0x80 } }, // 01001000 mshj.key
  {     0x07,       { 0x04, 0xc1, 0x9a, 0x62, 0x60, 0x83 },  { 0x66, 0x33, 0xa1, 0x49 },  { 0xc9, 0x16, 0x83, 0x84 } }, // 01001001 mshu.key
  {     0x07,       { 0x04, 0xc1, 0x3a, 0x63, 0x90, 0x23 },  { 0xf6, 0x93, 0xac, 0xe4 },  { 0x19, 0xd4, 0x87, 0x20 } }, // 01001010 mshvsf.key
  {     0x07,       { 0x04, 0xc1, 0x3a, 0x63, 0x90, 0x20 },  { 0x6f, 0x7a, 0x48, 0xc2 },  { 0x19, 0x7f, 0x1d, 0x28 } }, // 01001011 mshvsfa.key
  {     0x07,       { 0x04, 0xc1, 0x3a, 0x63, 0x90, 0x22 },  { 0x01, 0x1f, 0x3f, 0x6a },  { 0x4b, 0x8c, 0x59, 0x6c } }, // 01001100 mshvsfb.key
  {     0x07,       { 0x04, 0xc1, 0x3a, 0x63, 0x90, 0x22 },  { 0xd2, 0x87, 0x57, 0x00 },  { 0x8f, 0xda, 0x25, 0xf8 } }, // 01001101 mshvsfh.key
  {     0x07,       { 0x04, 0xc1, 0x3a, 0x63, 0x90, 0x20 },  { 0xb4, 0x1f, 0x91, 0x94 },  { 0x7e, 0x27, 0x0e, 0xe8 } }, // 01001110 mshvsfj.key
  {     0x07,       { 0x04, 0xc1, 0x3a, 0x63, 0x90, 0x20 },  { 0x53, 0x62, 0xbd, 0xce },  { 0x3a, 0x4a, 0xdb, 0x14 } }, // 01001111 mshvsfu.key
  {     0x07,       { 0x04, 0xc1, 0x3a, 0x62, 0x12, 0x03 },  { 0x93, 0x7a, 0x58, 0xe1 },  { 0xed, 0x69, 0x00, 0x48 } }, // 01010000 mvsc.key
  {     0x07,       { 0x04, 0xc1, 0x3a, 0x62, 0x12, 0x03 },  { 0xa2, 0xce, 0x82, 0x79 },  { 0x8d, 0xd4, 0x49, 0x3c } }, // 01010001 mvsca.key
  {     0x07,       { 0x04, 0xc1, 0x3a, 0x62, 0x12, 0x00 },  { 0x67, 0xb5, 0x0e, 0x2b },  { 0x5d, 0xac, 0xb8, 0x40 } }, // 01010010 mvscb.key
  {     0x07,       { 0x04, 0xc1, 0x3a, 0x62, 0x12, 0x03 },  { 0xdc, 0x63, 0x5a, 0x9f },  { 0x11, 0x78, 0xea, 0xe4 } }, // 01010011 mvsch.key
  {     0x07,       { 0x04, 0xc1, 0x3a, 0x62, 0x12, 0x00 },  { 0x35, 0xf1, 0x23, 0xa4 },  { 0x72, 0x1a, 0x0f, 0xd4 } }, // 01010100 mvscj.key
  {     0x07,       { 0x04, 0xc1, 0x3a, 0x62, 0x12, 0x02 },  { 0x80, 0x4e, 0x3d, 0xfb },  { 0x60, 0x8e, 0xd2, 0x58 } }, // 01010101 mvscu.key
  {     0x03,       { 0x70, 0x40, 0x00, 0x00, 0x1a, 0x1a },  { 0x81, 0x68, 0x3f, 0x02 },  { 0x8a, 0x2e, 0x60, 0x20 } }, // 01010110 nwarr.key
  {     0x03,       { 0x70, 0x40, 0x00, 0x00, 0x1a, 0x18 },  { 0x96, 0x18, 0x76, 0x70 },  { 0xc2, 0xc0, 0xa5, 0xc8 } }, // 01010111 nwarra.key
  {     0x03,       { 0x70, 0x40, 0x00, 0x00, 0x1a, 0x18 },  { 0x11, 0x51, 0xb3, 0xb6 },  { 0x42, 0x39, 0x8f, 0xa0 } }, // 01011000 nwarrb.key
  {     0x03,       { 0x70, 0x40, 0x00, 0x00, 0x1a, 0x18 },  { 0x10, 0x18, 0xa5, 0x52 },  { 0x03, 0x61, 0xa4, 0x8c } }, // 01011001 nwarrh.key
  {     0x03,       { 0x70, 0x40, 0x00, 0x00, 0x1a, 0x19 },  { 0xe1, 0x7b, 0x63, 0xf0 },  { 0xc2, 0xf9, 0x48, 0x20 } }, // 01011010 nwarru.key
  {     0x05,       { 0x04, 0xc0, 0xbb, 0xe1, 0x22, 0xc3 },  { 0xac, 0xa7, 0xc4, 0x30 },  { 0x0f, 0x5d, 0x2f, 0xa4 } }, // 01011011 pfghtj.key
  {     0x07,       { 0x70, 0x30, 0x04, 0x00, 0x10, 0x09 },  { 0xe7, 0xe0, 0x42, 0x71 },  { 0x47, 0x40, 0xca, 0xe4 } }, // 01011100 pgear.key
  {     0x02,       { 0x04, 0xc2, 0x17, 0x1b, 0x2c, 0x77 },  { 0x3e, 0xc3, 0x23, 0xdd },  { 0x8c, 0x6d, 0x67, 0x18 } }, // 01011101 progear.key
  {     0x02,       { 0x04, 0xc2, 0x17, 0x1b, 0x2c, 0x75 },  { 0xeb, 0x64, 0xee, 0xfc },  { 0x52, 0x35, 0x46, 0x98 } }, // 01011110 progeara.key
  {     0x02,       { 0x04, 0xc2, 0x17, 0x1b, 0x2c, 0x75 },  { 0xf7, 0x8b, 0x7e, 0x71 },  { 0xa8, 0xed, 0xfb, 0xe4 } }, // 01011111 progearj.key
  {     0x01,       { 0x04, 0xc3, 0x39, 0x66, 0x3e, 0xa0 },  { 0xb5, 0xb2, 0xc0, 0x8d },  { 0x20, 0x7c, 0xa8, 0x14 } }, // 01100000 pzloop2.key
  {     0x07,       { 0x04, 0xc3, 0x3a, 0x63, 0x90, 0x40 },  { 0x67, 0x83, 0x59, 0xbf },  { 0x39, 0x5c, 0x80, 0x68 } }, // 01100001 qndream.key
  {     0x04,       { 0x70, 0x30, 0x04, 0x00, 0x10, 0x0b },  { 0x02, 0x48, 0x8b, 0xa3 },  { 0x93, 0x80, 0xa6, 0x60 } }, // 01100010 ringdest.key
  {     0x04,       { 0x70, 0x30, 0x04, 0x00, 0x10, 0x0b },  { 0x02, 0x12, 0x8b, 0xa3 },  { 0x93, 0x80, 0xa6, 0x60 } }, // 01100011 ringdesta.key
  {     0x04,       { 0x70, 0x30, 0x04, 0x00, 0x10, 0x0b },  { 0x00, 0x73, 0x8b, 0xa3 },  { 0x93, 0x80, 0xa6, 0x60 } }, // 01100100 ringdesth.key
  {     0x05,       { 0x04, 0xc0, 0x9a, 0x80, 0xa6, 0x10 },  { 0x2d, 0x31, 0x7f, 0xb2 },  { 0x02, 0xaa, 0x13, 0x80 } }, // 01100101 rmancp2j.key
  {     0x05,       { 0x04, 0xc0, 0x9a, 0x02, 0x02, 0x38 },  { 0x39, 0x22, 0xa8, 0x23 },  { 0x39, 0x4d, 0xe6, 0x30 } }, // 01100110 rockman2j.key
  {     0x05,       { 0x04, 0xc0, 0x9a, 0x80, 0xa6, 0x13 },  { 0x61, 0x73, 0x90, 0x8d },  { 0xda, 0xea, 0x47, 0xc0 } }, // 01100111 sfa.key
  {     0x05,       { 0x04, 0xc2, 0x70, 0x33, 0x07, 0xa6 },  { 0x7e, 0x1f, 0x7f, 0x70 },  { 0xe7, 0xcd, 0x48, 0xfc } }, // 01101000 sfa2.key
  {     0x05,       { 0x04, 0xc2, 0x70, 0x33, 0x07, 0xa5 },  { 0x4a, 0x18, 0xbd, 0x45 },  { 0xa6, 0xf3, 0xf7, 0x60 } }, // 01101001 sfa2u.key
  {     0x05,       { 0x04, 0xc1, 0x18, 0xe0, 0x56, 0xbe },  { 0x0e, 0xec, 0x07, 0x90 },  { 0x1c, 0x4f, 0xf5, 0x58 } }, // 01101010 sfa3.key
  {     0x05,       { 0x04, 0xc1, 0x18, 0xe0, 0x56, 0xbd },  { 0xa5, 0x2d, 0xa2, 0x05 },  { 0x34, 0x0e, 0x10, 0xac } }, // 01101011 sfa3b.key
  {     0x05,       { 0x04, 0xc1, 0x18, 0xe0, 0x56, 0xbe },  { 0x1b, 0x17, 0xa3, 0x78 },  { 0xc7, 0xed, 0x10, 0x84 } }, // 01101100 sfa3h.key
  {     0x05,       { 0x04, 0xc1, 0x18, 0xe0, 0x56, 0xbc },  { 0x49, 0x30, 0xa7, 0x9a },  { 0x9c, 0x3f, 0x77, 0x9c } }, // 01101101 sfa3u.key
  {     0x05,       { 0x04, 0xc0, 0x9a, 0x80, 0xa6, 0x10 },  { 0x60, 0x0b, 0xcf, 0xa5 },  { 0xb2, 0xd5, 0xf6, 0x90 } }, // 01101110 sfau.key
  {     0x05,       { 0x04, 0xc2, 0x70, 0x33, 0x07, 0xa7 },  { 0x84, 0xa4, 0x7b, 0x08 },  { 0xbc, 0x5d, 0x0f, 0xd4 } }, // 01101111 sfz2a.key
  {     0x05,       { 0x04, 0xc3, 0x39, 0xc4, 0x22, 0x25 },  { 0x96, 0x11, 0x80, 0x80 },  { 0x2c, 0x0d, 0x3a, 0x3c } }, // 01110000 sfz2al.key
  {     0x05,       { 0x04, 0xc3, 0x39, 0xc4, 0x22, 0x24 },  { 0xe3, 0xd7, 0x07, 0xfc },  { 0x51, 0x4a, 0xcf, 0x38 } }, // 01110001 sfz2alb.key
  {     0x05,       { 0x04, 0xc3, 0x39, 0xc4, 0x22, 0x25 },  { 0x8c, 0x40, 0xc0, 0x10 },  { 0xfb, 0x6a, 0x3e, 0xa4 } }, // 01110010 sfz2alh.key
  {     0x05,       { 0x04, 0xc3, 0x39, 0xc4, 0x22, 0x26 },  { 0xc8, 0xd1, 0x40, 0x14 },  { 0x44, 0xc2, 0x8a, 0x64 } }, // 01110011 sfz2alj.key
  {     0x05,       { 0x04, 0xc2, 0x70, 0x33, 0x07, 0xa5 },  { 0xd3, 0x74, 0x7e, 0x1a },  { 0x66, 0x8b, 0x20, 0xd4 } }, // 01110100 sfz2b.key
  {     0x05,       { 0x04, 0xc2, 0x70, 0x33, 0x07, 0xa7 },  { 0xe4, 0x43, 0x7a, 0x69 },  { 0x0a, 0xd1, 0x46, 0x7c } }, // 01110101 sfz2h.key
  {     0x05,       { 0x04, 0xc2, 0x70, 0x33, 0x07, 0xa6 },  { 0x22, 0x13, 0xb9, 0x6e },  { 0x65, 0xf8, 0xbf, 0x04 } }, // 01110110 sfz2j.key
  {     0x05,       { 0x04, 0xc2, 0x70, 0x33, 0x07, 0xa4 },  { 0xed, 0x8b, 0x7a, 0x94 },  { 0xe4, 0x7f, 0x53, 0x1c } }, // 01110111 sfz2n.key
  {     0x05,       { 0x04, 0xc1, 0x18, 0xe0, 0x56, 0xbd },  { 0xf8, 0xd0, 0x9c, 0x96 },  { 0x03, 0x27, 0x42, 0x64 } }, // 01111000 sfz3a.key
  {     0x05,       { 0x04, 0xc1, 0x18, 0xe0, 0x56, 0xbe },  { 0x7a, 0xd1, 0xf4, 0xc3 },  { 0x00, 0x7e, 0x4a, 0xf8 } }, // 01111001 sfz3j.key
  {     0x05,       { 0x04, 0xc0, 0x9a, 0x80, 0xa6, 0x13 },  { 0xf9, 0x67, 0x61, 0x18 },  { 0x42, 0x8e, 0xf0, 0x9c } }, // 01111010 sfza.key
  {     0x05,       { 0x04, 0xc0, 0x9a, 0x80, 0xa6, 0x10 },  { 0x05, 0x8d, 0x25, 0x7b },  { 0x2f, 0x6a, 0x0b, 0xdc } }, // 01111011 sfzb.key
  {     0x05,       { 0x04, 0xc0, 0x9a, 0x80, 0xa6, 0x12 },  { 0x2f, 0xc9, 0x14, 0xea },  { 0x71, 0xc3, 0x5b, 0x84 } }, // 01111100 sfzh.key
  {     0x05,       { 0x04, 0xc0, 0x9a, 0x80, 0xa6, 0x12 },  { 0x8b, 0xc1, 0xe5, 0x0d },  { 0x79, 0xa3, 0x36, 0xc4 } }, // 01111101 sfzj.key
  {     0x05,       { 0x04, 0xc0, 0xbb, 0xe1, 0x22, 0xc1 },  { 0xfb, 0x77, 0xc1, 0xe9 },  { 0xba, 0x4b, 0x10, 0x84 } }, // 01111110 sgemf.key
  {     0x05,       { 0x04, 0xc0, 0xbb, 0xe1, 0x22, 0xc3 },  { 0x26, 0x5d, 0xf8, 0x8d },  { 0x52, 0x0b, 0x42, 0x40 } }, // 01111111 sgemfa.key
  {     0x05,       { 0x04, 0xc0, 0xbb, 0xe1, 0x22, 0xc0 },  { 0x91, 0x2f, 0xc4, 0xfb },  { 0x63, 0x97, 0x1a, 0x04 } }, // 10000000 sgemfh.key
  {     0x04,       { 0x70, 0x30, 0x04, 0x00, 0x10, 0x0b },  { 0x00, 0xa3, 0x03, 0xa2 },  { 0x41, 0x00, 0xa6, 0x60 } }, // 10000001 smbomb.key
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
void loop() {
}

void send_byte(uint8_t data) {
  for(int8_t bit_num = 7; bit_num >= 0;bit_num--) { 
    uint8_t bit = data & masks[bit_num];
    if(bit) {
      SET_DATA;
    } else {
      CLR_DATA;
    }
    
    SET_CLOCK;
    CLR_CLOCK;
  }
}

// JP1 = PA7 = bit7
// JP2 = PA6 = bit6
// JP3 = PA5 = bit5
// JP4 = PA6 = bit4
// JP5 = PA0 = bit3
// JP6 = PA1 = bit2
// JP7 = PA2 = bit1
// JP8 = PA3 = bit0
uint8_t read_jumpers() {
  uint8_t jumpers = 0;
  uint8_t raw;
  uint8_t bit;

  // negate the bits since we are using
  // pull-ups, jumper'd will be low
  raw = PORTA.IN ^ 0xff;

  // upper nible is in the correct order, but lower isnt
  jumpers = raw & 0xf0;

  // reverse the order of the lower nibble
  bit = (raw & 0x1) << 3;
  jumpers = jumpers | bit;

  bit = (raw & 0x2) << 1;
  jumpers = jumpers | bit;

  bit = (raw & 0x4) >> 1;
  jumpers = jumpers | bit;

  bit = (raw & 0x8) >> 3;
  jumpers = jumpers | bit;

  return jumpers;
}

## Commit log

2022-10-12 Add openkey-kicad-library as submodule
2022-10-12 Initial check of board/firmware
    [openkey-cps2.kicad_pcb, openkey-cps2.kicad_sch]
2022-10-12 Move firmware to openkey-cps2 sub dir to keep arduino ide happy
2022-10-12 Set output path for gerber files, other minor tweaks
    [openkey-cps2.kicad_pcb]
2022-10-12 Add gerber export directories to .gitignore
2022-10-27 Some minor tweaks around the vcc jumper and pad
    Should make it more obvious what is for what
    [openkey-cps2.kicad_pcb]
2022-10-27 bump rev number
    [openkey-cps2.kicad_pcb]
2022-11-13 Initial support for 93646B-3/4 revision boards
    [openkey-cps2.kicad_pcb, openkey-cps2.kicad_sch]
2022-11-25 HW: Add support for 93646B-3/4 and 97691A-3/4. Add UPDI header.
    [openkey-cps2.kicad_pcb, openkey-cps2.kicad_sch]
2022-11-26 HW: adjust a couple traces
    [openkey-cps2.kicad_pcb]
2022-11-27 HW: get most everything 0.25mm aligned
    [openkey-cps2.kicad_pcb]
2022-12-08 HW: tweak so a VCC trace isn't so close to edge
    [openkey-cps2.kicad_pcb]
2022-12-17 HW: somehow missed connecting the ground pad, doh
    [openkey-cps2.kicad_pcb]
2022-12-29 Add panel
    [openkey-cps2-panel.kicad_pcb]
2023-01-04 HW: bypass cap value typo'd as 100uf when it should be 100nf
    Thanks for hatmoose for pointing out the typo
    [openkey-cps2-panel.kicad_pcb, openkey-cps2.kicad_pcb, openkey-cps2.kicad_sch]
2023-01-15 Docs: additional info around castellated holes
    thanks to hatmoose for the picture
2023-10-14 Increase startup delay
    User Tailsnic reported that openkey wasn't programming
    on one of his cabinets (powersupply issue?). Through
    some testing he found if he increased the start up delay
    (arduino ide) and the initial delay() in the code it
    started working.
    Since programming holds the board in reset, inceasing
    these values shouldn't cause any issues for everyone
    else.
    [openkey-cps2.ino]
2026-05-20 panel + assembly updates
    - have kikit create the panel (was done by hand before)
    - have jlcpcb fabrication plugin create bom/positions files for the panel
    - create PANEL.md with instructions for having jlcpcb assemble the board
    - update kicad files to 10.x
    [openkey-cps2-panel.kicad_pcb, openkey-cps2.kicad_pcb, openkey-cps2.kicad_sch]
